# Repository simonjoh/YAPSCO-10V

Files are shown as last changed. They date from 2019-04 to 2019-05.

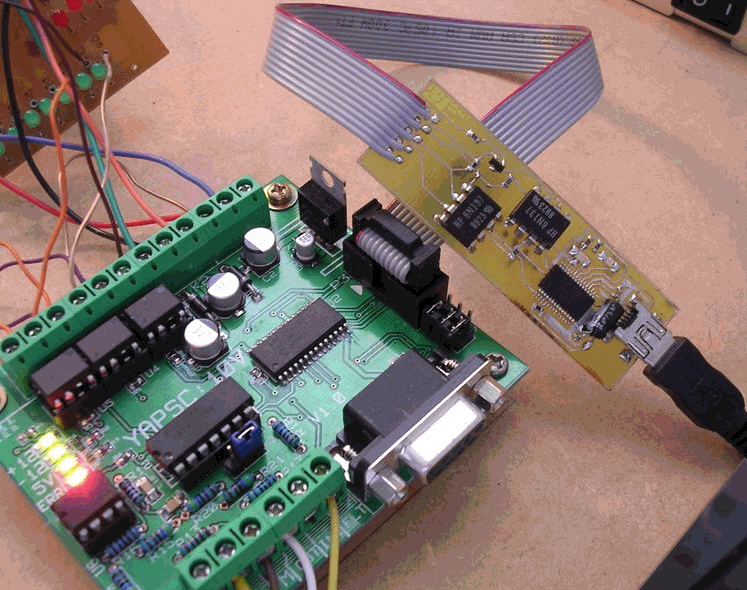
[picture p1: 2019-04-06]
YAPSC.10V Doc/PCB/2side-photo2.gif

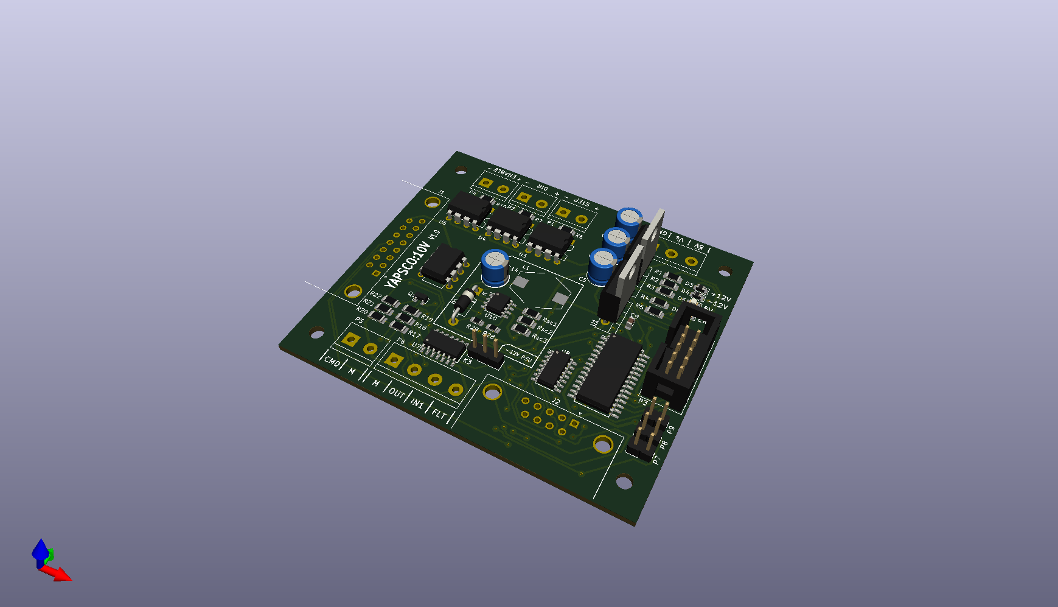
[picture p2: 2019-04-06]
schema_pcb/YAPSCO.png

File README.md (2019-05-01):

# YAPSCO-10V
Modification of the YAPSC:10V with onboard -12V supply.

The board has the same outer dimensions and mounting hole positions as YAPSC:10V, so a drop-in replacement should be quite easy.

## Specifications
* Input voltage +12V..+24V
* Same as YAPSC:10V

## Schematic and PCB
Most of the schematic symbols have been updated with new ones from Kicad's library.

Some PCB footprints have been replaced with surface mounted versions to be able to squash in the -12V supply while keeping the board outline and mounting holes the same as YAPSC:10V.

The DB15 connector footprint has also been added to the PCB layout so that it can easily be soldered onto the board if needed.

The PCB now includes a DC-DC voltage inverter set to -12V, but can be adjusted as necessary with 2 feedback resistors (R28, R29). Component values for the DC-DC converter can be calculated with the SMath sheet "Calc MC33063.sm".

## Everything else
The firmware has not been modified and connectors are generally kept in the original places.

## Disclaimer
The board is being manufactured and therefore have not been tested yet. The only thing I have tested, is the DC-DC controller on a breadboard, but since everything has mainly been kept as the original it should just work right out of the box, right? :)

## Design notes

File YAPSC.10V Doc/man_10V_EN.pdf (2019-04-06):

# YAPSC : 10V

### Users' manual

Yet Another dsPic Servo Controller – 10V Page 1/15

## Table Of Content

Page 2/15 Yet Another dsPic Servo Controller – 10V

## 1 Introduction - before you start

YAPSC:10V allows the use of analog-operated servo amplifiers, either torque or speed controlled. This board takes STEP/DIR position command from the PC (MACH3, EMC etc.), position feedback from a quadrature encoder, and outputs an analog command to the servo amp.
Please note the difference between YAPSC and YAPSC:10V. These two projects share a part of the dsPic's source code but the manuals are different! YAPSC is a board WITH a power stage to control DC servos; whereas YAPSC:10V has no power stage and cannot drive a servomotor without a servo power amplifier.
If you are looking for the DC servomotor controller, this is not the right manual you are looking into! You will find links at the end of this document for each versions of YAPSC.
Below are the two big scheme of YAPSC:10V application:

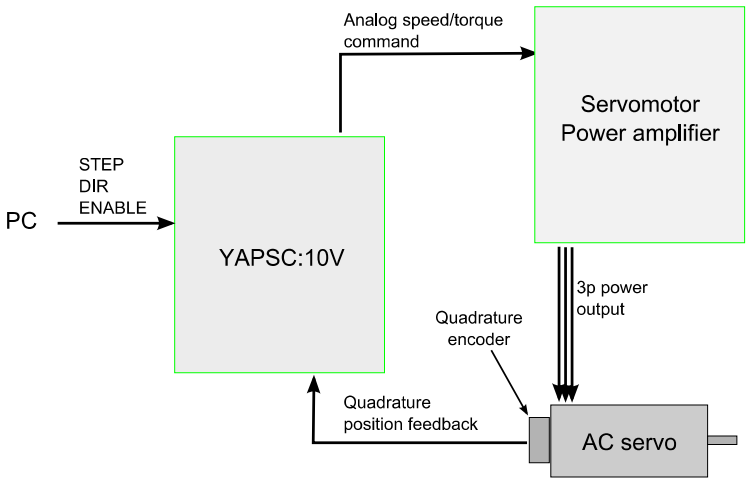
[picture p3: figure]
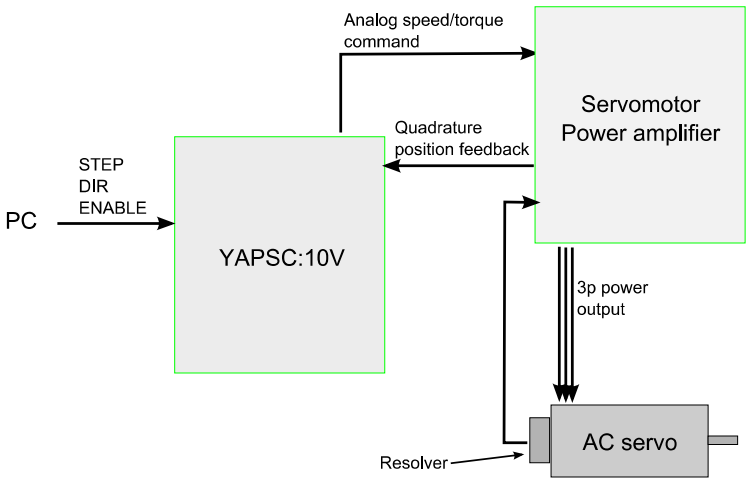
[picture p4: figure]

## 2 Features

- Takes position feedback from quadrature encoder on the servo (resolvers cannot be used directly but some amps can output quadrature signals from the resolver feedback)
- Compatible with both torque and speed controlled amps
- Takes STEP/DIR command from PC
- ENABLE signal from PC can disable the amp
- Output amplitude can be selected from +/-0V to +/-10V, to feed +/-10V or +/-5V amps
- Jumper selected TTL or differential quadrature encoder input
- FAULT input from the servo amp
- Reset/ENABLE output to the servo amp
- One additional input for future use
- Programmable max error limit : 0 (disabled) to 32768
- PID tuning program for linux, windows (and probably Mac OS) : YTT (under development)
- STEP/DIR input multiplier (allows faster speed)
- 1MHz max step and encoder rate!

## 3 Physical Description

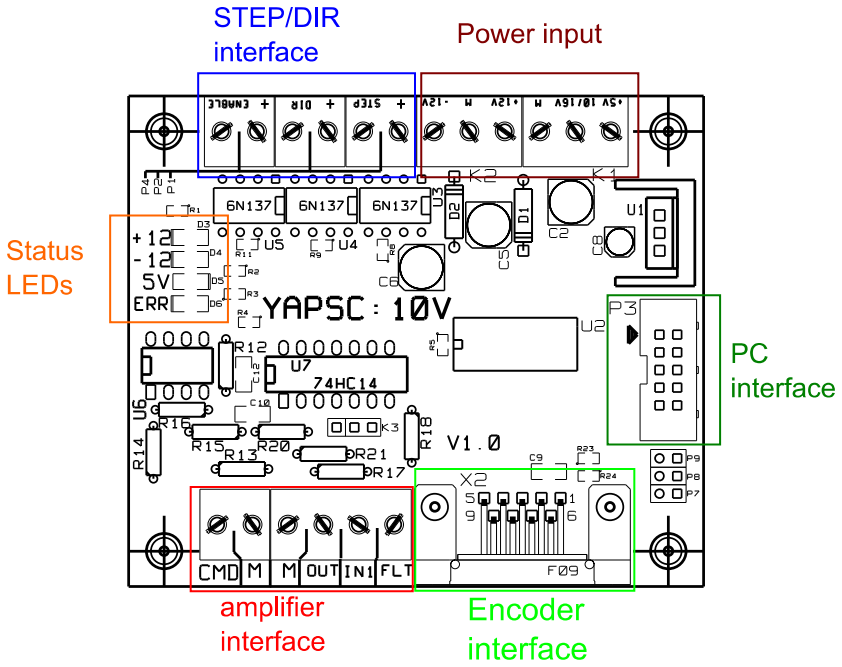
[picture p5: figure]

## 3.1 Status LEDs

There are 4 LEDs on the board:

Page 4/15 Yet Another dsPic Servo Controller – 10V

3.1.1 +12V
Green LED. Lit when the OpAmp +12V supply is present.

3.1.2 -12V
Green LED. Lit when the OpAmp -12V supply is present.

3.1.3 5V
Green LED. Lit when the dsPIC +5V is present

### 3.1.4 ERR

This LED is dark under normal operation.

### 3.1.4.1 Power up

During power up, ERR LED is lit during he power-up procedure. If the ERR led is stuck and the amplifier is disabled, connect the Prog. Key and open a serial terminal. Cycle the power OFF and ON. You should read the initialization status and see where the process blocks.

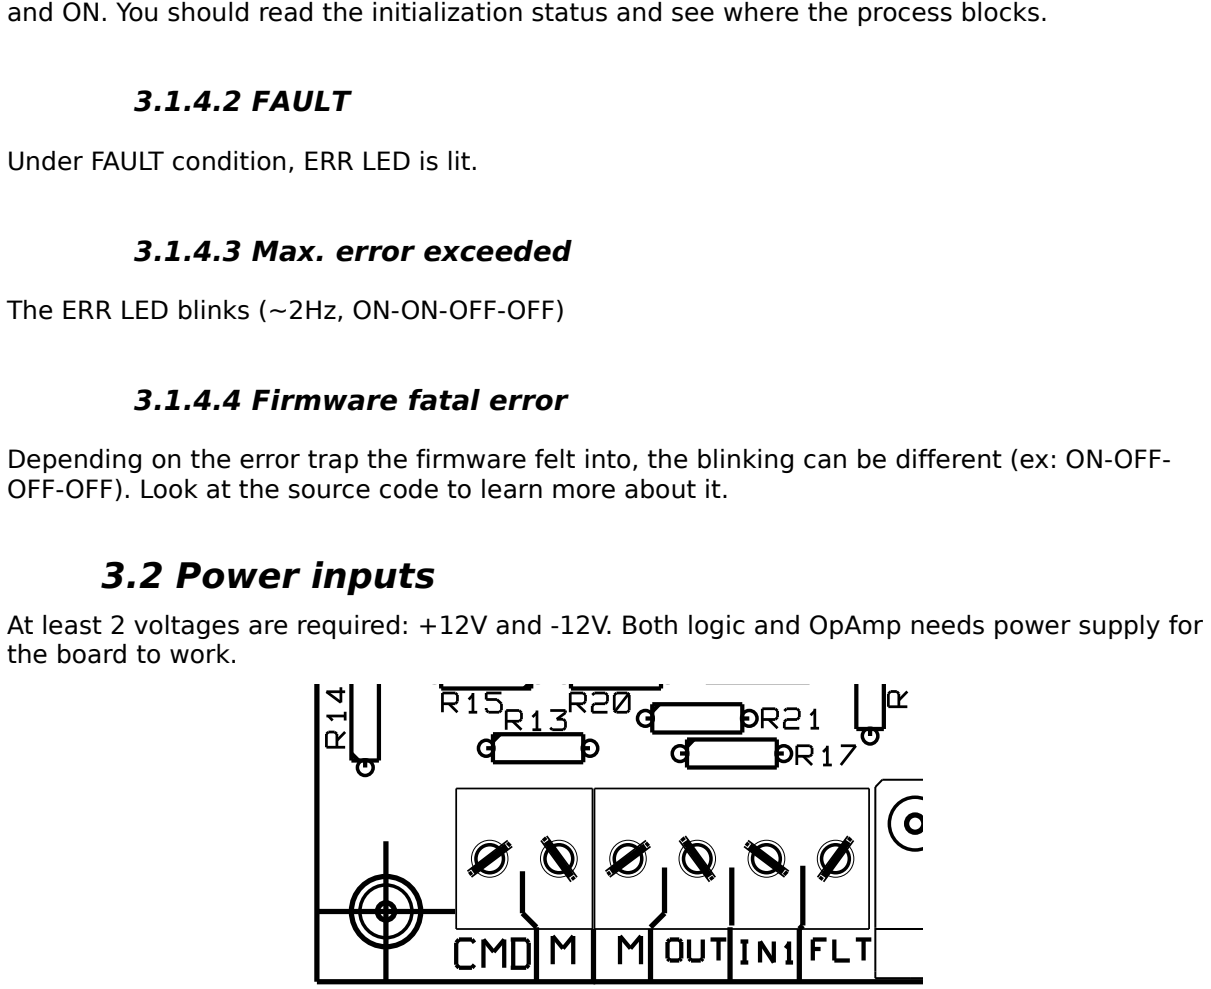
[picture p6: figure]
3.1.4.2 FAULT; Under FAULT condition, ERR LED is lit.; 3.1.4.3 Max. error exceeded; 3.1.4.4 Firmware fatal error; 3.2 Power inputs; the board to work.

The ERR LED blinks (~2Hz, ON-ON-OFF-OFF)

Depending on the error trap the firmware felt into, the blinking can be different (ex: ON-OFF-OFF-OFF). Look at the source code to learn more about it.

At least 2 voltages are required: +12V and -12V. Both logic and OpAmp needs power supply for

### 3.2.1 K1

K1 is the logic power supply input.

3.2.1.1 +5V

Logic +5V supply. You can connect it directly to a 5V power source, or use the regulated voltage from 10 to 16V input to supply 5V to other logic/boards. The board's power consumption is maximum 300mA plus encoder consumption (generally ~10-20mA)

### 3.2.1.2 M

Common ground

3.2.1.3 10/16V

Input to the LM7805 voltage regulator. 10 to 16V, max 300mA + encoder consumption

### 3.2.2 K2

K2 is the OpAmp supply voltage input.

3.2.2.1 +12V

12 to 16V positive supply. 30mA max consumption

3.2.2.2 -12V

-16 to -12V negative supply. 30mA max consumption

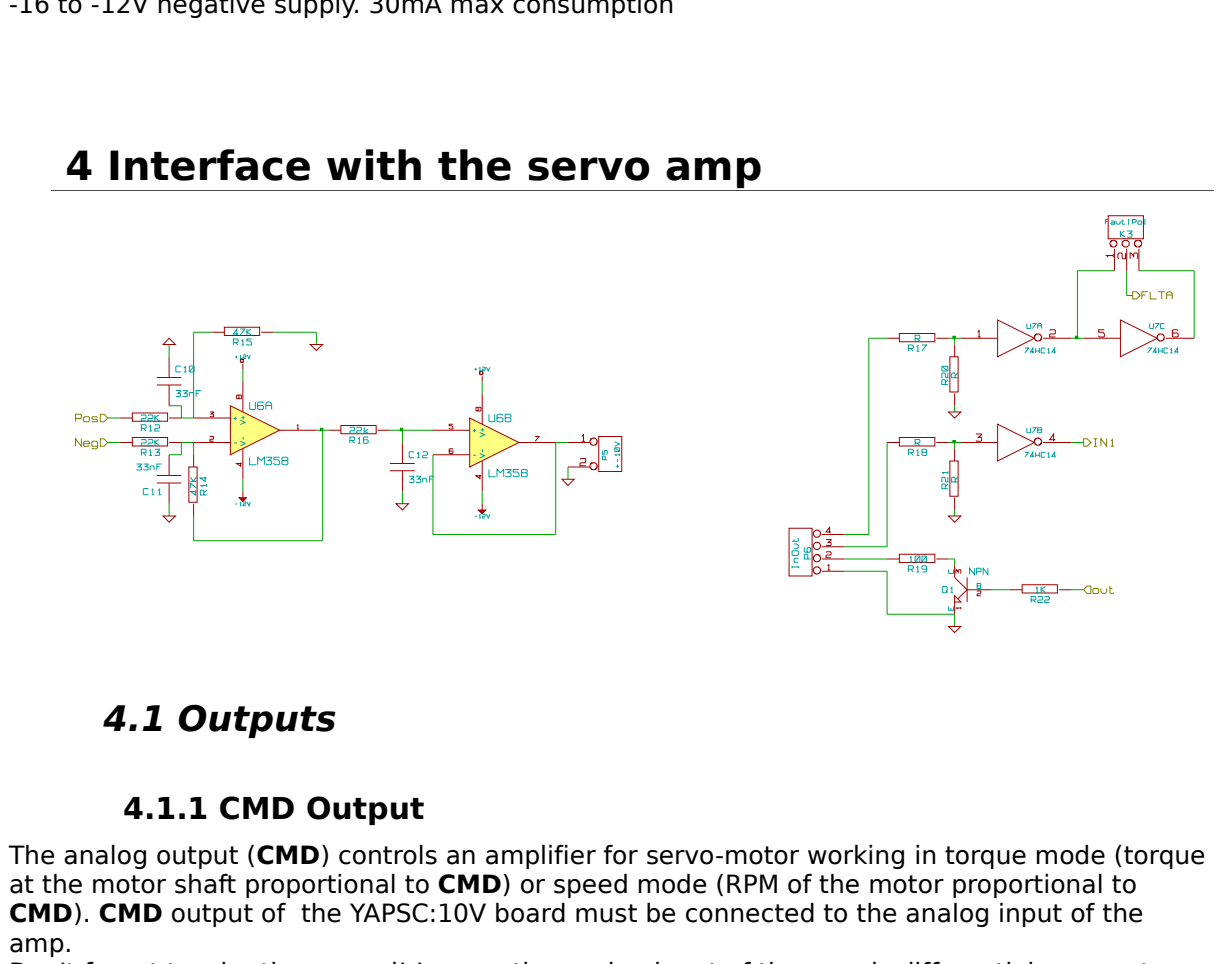
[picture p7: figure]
4 Interface with the servo amp; 4.1 Outputs; 4.1.1 CMD Output; amp.

The analog output (CMD) controls an amplifier for servo-motor working in torque mode (torque at the motor shaft proportional to CMD) or speed mode (RPM of the motor proportional to CMD). CMD output of the YAPSC:10V board must be connected to the analog input of the

Don't forget to wire the ground! In case the analog input of the amp is differential, connect

Page 6/15 Yet Another dsPic Servo Controller – 10V

CMD to the + (positive) input and the ground M on the – (negative) input of the amp. For differential input amp, you must use two wires, one for the ground M and the other for CMD. Those two cables must be at least twisted, but it's better to have them twisted and shielded. You must, independently of those two wires, link a cable (min. 0,5mm² section area) between M and the amp's ground

### 4.1.2 OUT output

The “OUT” output is an open-collector output, designed to drive 0-30V 100mA loads, such as relays etc.
To come : example schematics

### 4.1.2.1 Enable/Reset

Under running conditions (i.e motor is powered and YAPSC taking STEP/DIR commands), OUT is forced low.
If YAPSC is disabled (see section 5.2.1), the OUT output is floating.
If a FAULT condition is detected (look in section 4.2.1), then OUT will be floating and the ERROR led will blink.

## 4.2 Inputs

There are two Schmitt-trigger (digital) inputs which can be configured.
By changing the values of (R17,R20) and (R18/R21) the two inputs can work with 5V, 12V or 24V logic:
5V logic | 24V logic
R17 = R18 = 1KΩ | R17 = R18 = 39,2KΩ
R20 = R21 = 47KΩ | R20 = R21 = 10KΩ
Low level : L = 2,5V | Low level : L = 12V
High level : H = 3V | High level : H = 15V

### 4.2.1 FLT input

This input is the feedback from the servo amp. In case that a problem (overtemp, overvoltage, ...) is detected by the amp, it can notify YAPSC. On a FAULT condition, YAPSC:10V goes into disabled mode : CMD=0 and the STEP/DIR commands are ignored.
FLT input can be configured either to be active-low or active high:
Polarity : | Active high | Active low
K3 strap position: | 1 – 2 | 2 – 3
Fault operation: | If FLT is High, FAULT condition If FLT is Low, normal operation | If FLT is Low, FAULT condition If FLT is High, normal operation

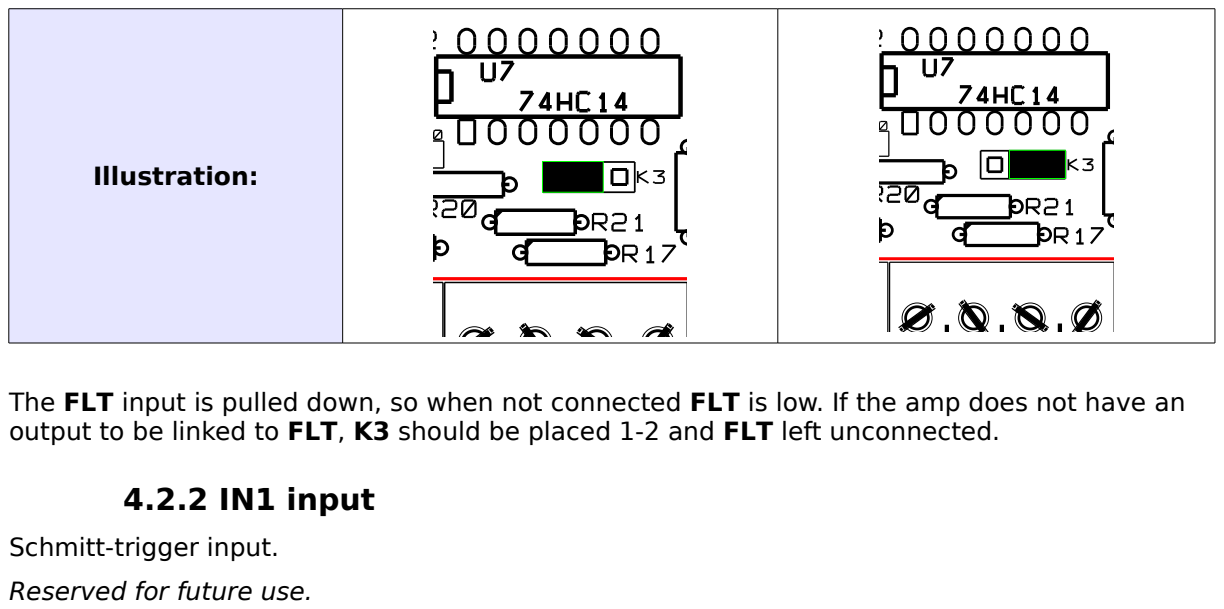
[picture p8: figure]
Illustration:; 4.2.2 IN1 input; Schmitt-trigger input.; Reserved for future use.

The FLT input is pulled down, so when not connected FLT is low. If the amp does not have an output to be linked to FLT, K3 should be placed 1-2 and FLT left unconnected.

## 5 Interface with the computer

## 5.1 HE10

HE10 connector P3 provides all the following:

### 5.1.1 RS232 port

For configuring YAPSC:10V via a serial port terminal (I.e hyperterminal on Windows) or via YTT (read section 8.1).
Pin 6 (RXD) : data in
Pin 5 (TXD) : data out
Port configuration : 9600bps, 8n, 1stop, no flow control.
The RS232 pins are NOT optoisolated! For maximum security, please | use the
optoisolated USB prog. | key.

### 5.1.2 ICSP

The dsPIC30F4012 can be programmed via an ICD2, pickit2 or other programming tool. The program can also be debugged under operation with Microchip's ICD2/3 (or other compatible tools).
Pin 2 : MCLR Master Clear

Page 8/15 Yet Another dsPic Servo Controller – 10V

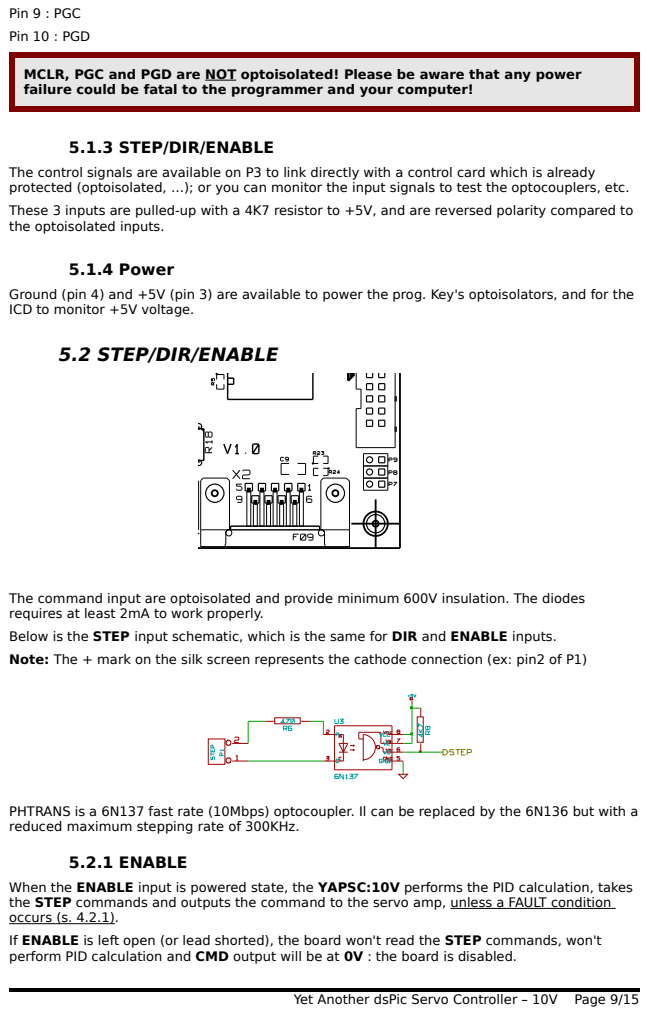
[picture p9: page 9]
Pin 9 : PGC; Pin 10 : PGD; 5.1.4 Power; 5.2.1 ENABLE

MCLR, PGC and PGD are NOT optoisolated! Please be aware that any power
failure could be fatal to the programmer and your computer!

5.1.3 STEP/DIR/ENABLE

The control signals are available on P3 to link directly with a control card which is already
protected (optoisolated, …); or you can monitor the input signals to test the optocouplers, etc.
These 3 inputs are pulled-up with a 4K7 resistor to +5V, and are reversed polarity compared to
the optoisolated inputs.

Ground (pin 4) and +5V (pin 3) are available to power the prog. Key's optoisolators, and for the
ICD to monitor +5V voltage.

5.2 STEP/DIR/ENABLE

The command input are optoisolated and provide minimum 600V insulation. The diodes
requires at least 2mA to work properly.
Below is the STEP input schematic, which is the same for DIR and ENABLE inputs.
Note: The + mark on the silk screen represents the cathode connection (ex: pin2 of P1)

PHTRANS is a 6N137 fast rate (10Mbps) optocoupler. Il can be replaced by the 6N136 but with a
reduced maximum stepping rate of 300KHz.

When the ENABLE input is powered state, the YAPSC:10V performs the PID calculation, takes
the STEP commands and outputs the command to the servo amp, unless a FAULT condition
occurs (s. 4.2.1 ).
If ENABLE is left open (or lead shorted), the board won't read the STEP commands, won't
perform PID calculation and CMD output will be at 0V : the board is disabled.

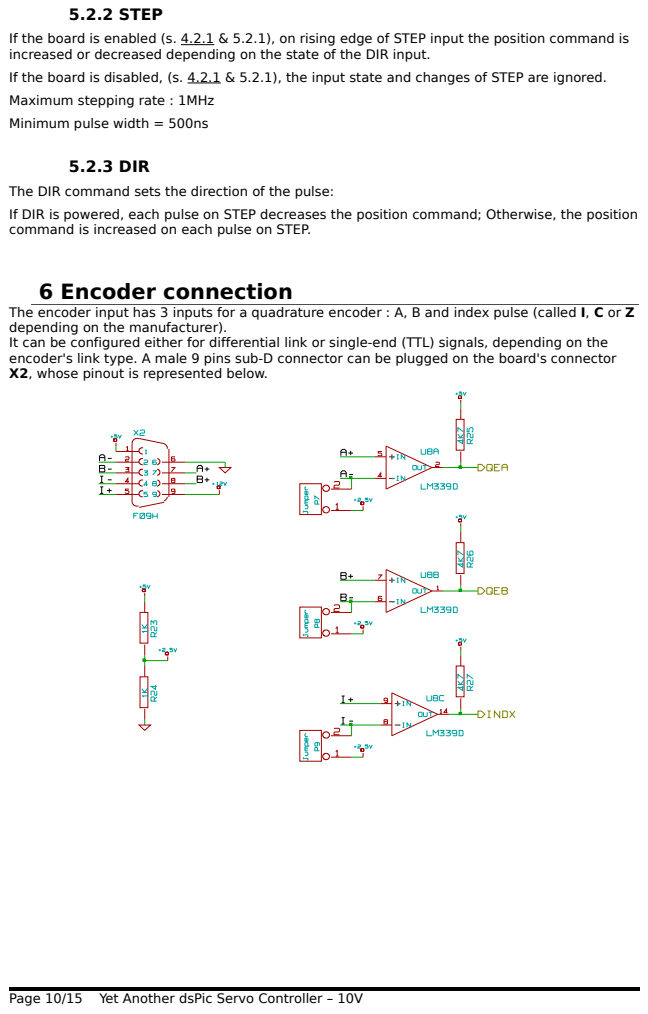
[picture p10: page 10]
5.2.2 STEP; 5.2.3 DIR

If the board is enabled (s. 4.2.1 & 5.2.1), on rising edge of STEP input the position command is
increased or decreased depending on the state of the DIR input.
If the board is disabled, (s. 4.2.1 & 5.2.1), the input state and changes of STEP are ignored.
Maximum stepping rate : 1MHz
Minimum pulse width = 500ns

The DIR command sets the direction of the pulse:
If DIR is powered, each pulse on STEP decreases the position command; Otherwise, the position
command is increased on each pulse on STEP.

6 Encoder connection
The encoder input has 3 inputs for a quadrature encoder : A, B and index pulse (called I, C or Z
depending on the manufacturer).
It can be configured either for differential link or single-end (TTL) signals, depending on the
encoder's link type. A male 9 pins sub-D connector can be plugged on the board's connector
X2, whose pinout is represented below.

Page 10/15 Yet Another dsPic Servo Controller – 10V

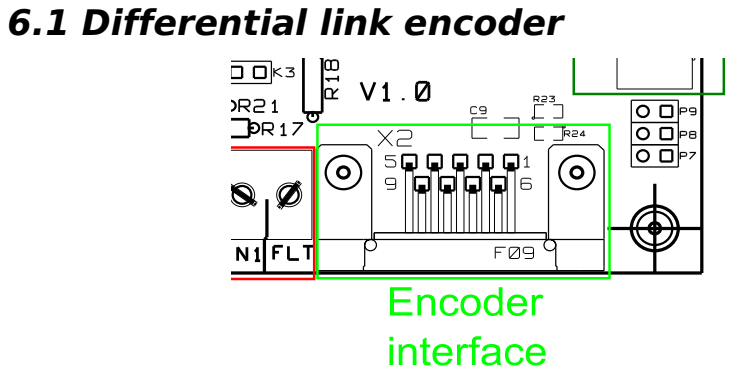
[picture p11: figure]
6.1 Differential link encoder

- Remove P7 , P8 and P9
- Link A+/A- to the A output of the encoder, B+/B- to the B output of the encoder
- Link I+/I- to the index output C (can be called Z or I) of the encoder, if present
- Link the ground (or negative supply) of the encoder to the sub-D9's pin number 6
- Depending on the supply voltage required by the encoder, link the +5V or +12V (sub-D9's pins 1 or 9) to the positive supply of the encoder
- Once the encoder cord is fully linked, you can plug the connector onto YAPSC:10V's X2 connector.
You should note that:
- If the encoder allows it (check the corresponding datasheet), link a 120Ohms resistor between A+ and A-; between B+ and B- and between I+ and I- as close as possible to the sub-D9 plug used to make the encoder cord. This will help noise immunity.
- Contrary to +5V supply, the +12V supply is NOT a regulated voltage. It comes directly from K1 connector, so you should check that this voltage meets the encoder's specifications.

## 6.2 TTL Encoder

- Place P7, P8 et P9
- Link A+ th the A output of the encoder, B+ to the B output of the encoder. A- and Bare not linked
- Link I+ to the index output of the encoder (Called C, I or Z) if present on the encoder. Iis not linked
- Link the ground (or negative supply) of the encoder to the sub-D9's pin number 6
- Depending on the supply voltage required by the encoder, link the +5V or +12V (sub-D9's pins 1 or 9) to the positive supply of the encoder
- Once the encoder cord is fully linked, you can plug the connector onto YAPSC:10V's X2

connector.

Do NEVER link a differential link encoder while P7, P8 or P9 are in position! The encoder could be damaged if that was the case!

Note:
- You may have to place capacitors (100uF+1uF electro +100nF ceramic) between the encoder's ground and positive supply if the cables between the encoder and YAPSC:10V is long, and more generally if the encoder is sensitive to electrical noise.
- If the encoder needs a very precise +5V regulated power supply, do not use the 5V output (pin 1) but rather use a LM7805 type regulator and its capacitors as close to the encoder as possible. This regulator will be powered by the +12V (pin9).

## 7 Configuring the board

Each commands are sent trough the RS232 port and validated by pressing the [ENTER] key (serial port sends “\r\n” to the board).
This section refers to RS232-terminal configuration; A dedicated software called YTT (YAPSC Tuning Tool) eases the configuration of the board (look in section 8).
Here are the available commands:

### 7.1.1 PID gains

P sets the P gain (usally P=0,001 to 0,1)
I sets the I gain (usally I=0,0001 to 0,01) D sets the D gain (usally P=0,0001 to 0,01) EXAMPLE:
P0,001
I0,0001
D0

### 7.1.2 Maximal error

This parameter is the error (in pulses; ie lines *4) over which the amp is disabled (no torque). Send the L command :
L1024
Sets the max. error to 1024 pulses (=256 lines)

NOTE: following command disables the max error monitoring. Please do not use this mode unless you are absolutely sure of what you are doing!
L0

NOTE: When the maximum error is reached, the ERROR led blinks and the error is reported on the serial port. To reset the board, you have to cycle power OFF and ON or to reset the board (short MCLR and GND pins, see section 5.1.2)

Page 12/15 Yet Another dsPic Servo Controller – 10V

### 7.1.3 Maximum output

To match the output swing to any type of amplifier, the output swing can be limited. The output swing is expressed in percent of 10,5V:
M50
Will set the output swing to +5,25/-5,25V
M95
Sets the output swing to +10V/-10V

### 7.1.4 STEP input multiplier

For fast displacements, the 1MHz STEP limit of the interpolator's maximum STEP rate (ex: MACH3 is limited to ~30-40KHz on the parallel port) may not be enough. If the resolution can be reduced, you can set the multiplier to a higher value than 1.
EXAMPLE:
X2
Multiply the STEP inputs by 2. Each pulse on STEP will move the motor's position of 2 pulses (½ line)
EXEMPLE:
X-1
Inverts the direction. It is equivalent to invert the DIR input.

## 8 Annex

## 8.1 YTT (YAPSC Tuning Tool)

YTT is currently under development and has no web page. Check the YAPSC:10V (http://www.cnczone.com/forums/showthread.php?t=74532) tread for latest news.

## 8.2 YAPSC

The first version of YAPSC is a DC servomotor controller equipped with a power stage. Links:
- Original tread on the French forum usinages.com : www.usinages.com/carte-servos-adspic-t648.html (http://www.usinages.com/carte-servos-a-dspic-t648.html)
- YAPSC-related stuff on my web page (French) : http://max-mod-shop.com/index.php?option=com_content&view=category&id=17:-yapsc&Itemid=4&layout=default (http://max-mod-shop.com/index.php?option=com_content&view=category&id=17:-yapsc&Itemid=4&layout=default)
- dspic-servo tread on cnczone.com : http://www.cnczone.com/forums/showthread.php?t=40940 (http://www.cnczone.com/forums/showthread.php?t=40940)

## 8.3 dspic-servo

This is the original work from Lawrence Glaister I based YAPSC on. It is located at http://www.members.shaw.ca/swstuff/dspic-servo.html

## 8.4 Licence

Unless specified, the project files are released under GPL3. Read the included file gpl-3.0-standalone.html

This manual is NOT under GPL, I (Charles-Henri Maximilien MOUSSET) reserve all right on it. Copying or modifying in any way (partially or entirely) this manual's content is forbidden unless I explicitly authorize you to do so.
You can freely distribute this manual under the same condition, unmodified and without any material of financial compensation.

## 8.5 Contact

Maximilien MOUSSET
max-mod@max-mod-shop.com
PM “MaX-MoD” on cnczone,com PM “MaX-MoD” on usinages.com

Page 14/15 Yet Another dsPic Servo Controller – 10V

## Document Rev

Date | Description
04/04/09 | Corrected board silkscreen on power input connector

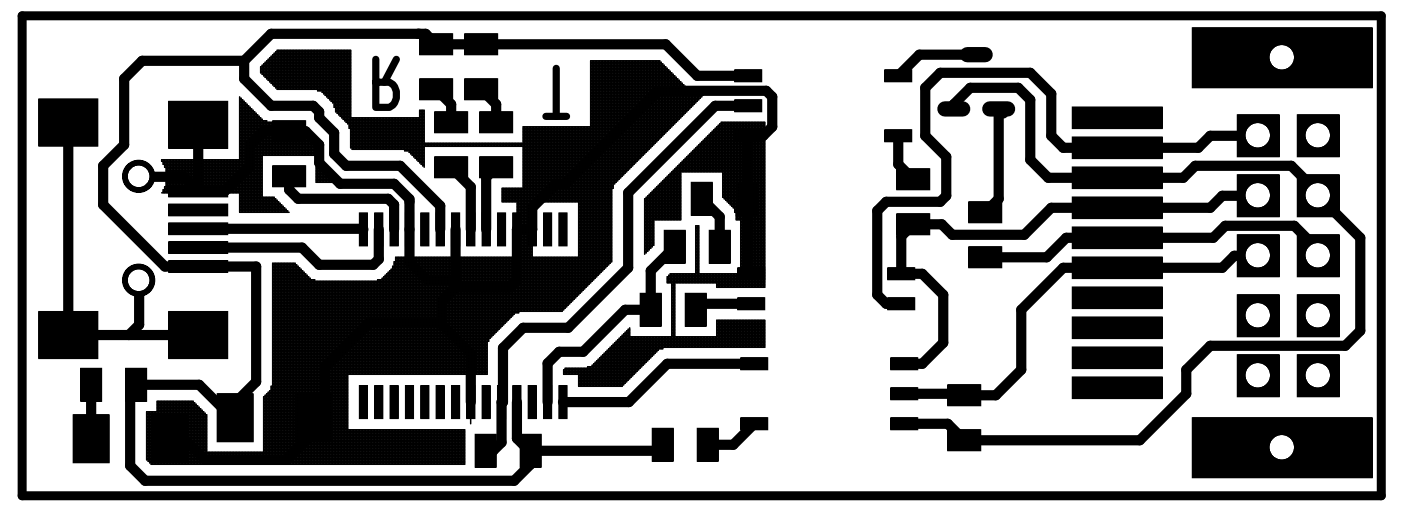
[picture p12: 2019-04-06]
YAPSC.10V Doc/PCB/USB.bmp

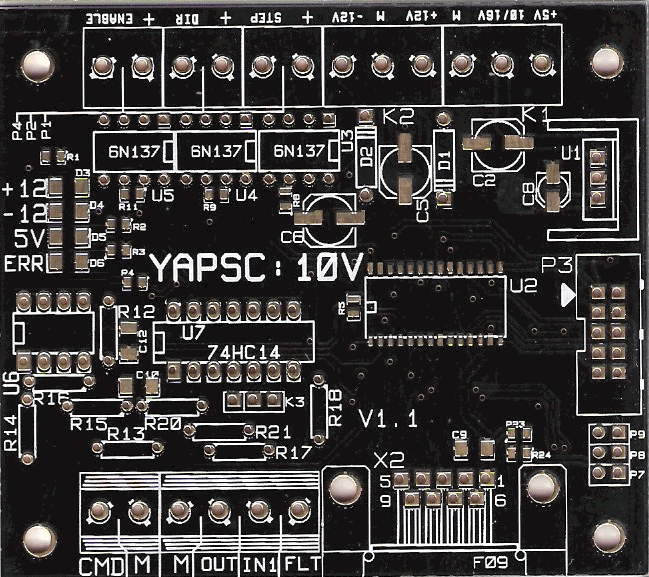
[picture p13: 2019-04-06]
YAPSC.10V Doc/PCB/1side-photo1.gif

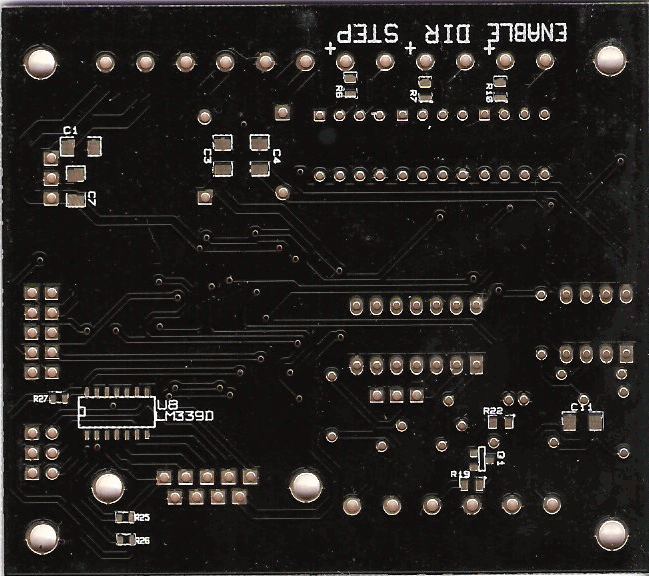
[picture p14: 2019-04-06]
YAPSC.10V Doc/PCB/2side-photo1.gif

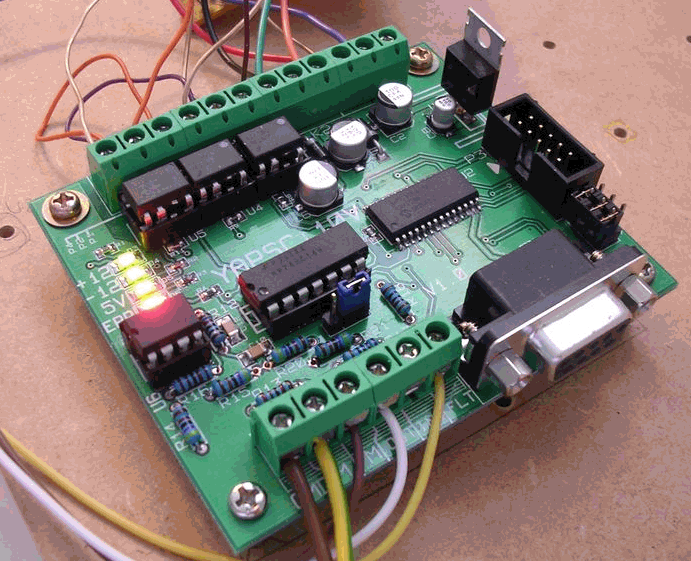
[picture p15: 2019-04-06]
YAPSC.10V Doc/PCB/1side-photo2.gif

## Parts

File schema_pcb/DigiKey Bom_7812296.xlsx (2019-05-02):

Manufacturer Part Number | Manufacturer | Digi-Key Part Number | Customer Reference | Reference Designator | Packaging | Part Status | Quantity | Unit Price | Extended Price | Quantity Available | Mfg Std Lead Time | Description | RoHS Status | Lead Free Status | REACH Status | US Tariff Status
OSTTC032162 | On Shore Technology Inc. | ED2610-ND |  |  | Bulk | Active | 1 | 5.61 | kr.5.61 | 52062 | 12 Weeks | TERM BLK 3P SIDE ENT 5.08MM PCB | RoHS Compliant | Lead free | REACH Unaffected | Tariff Applied
OSTTC022162 | On Shore Technology Inc. | ED2609-ND |  |  | Bulk | Active | 6 | 5.28 | kr.31.68 | 63751 | 12 Weeks | TERM BLK 2P SIDE ENT 5.08MM PCB | RoHS Compliant | Lead free | REACH Unaffected | Tariff Applied
885012207069 | Wurth Electronics Inc. | 732-8058-1-ND |  |  | Cut Tape (CT) | Active | 3 | 0.73 | kr.2.19 | 3880 | 37 Weeks | CAP CER 0.033UF 25V X7R 0805 | RoHS Compliant | Lead free | REACH Unaffected
885012207083 | Wurth Electronics Inc. | 732-8065-1-ND |  |  | Cut Tape (CT) | Active | 1 | 0.73 | kr.0.73 | 1263 | 37 Weeks | CAP CER 330PF 50V X7R 0805 | RoHS Compliant | Lead free | REACH Unaffected
LTST-S220GKT | Lite-On Inc. | 160-1218-1-ND |  |  | Cut Tape (CT) | Active | 3 | 1.78 | kr.5.34 | 85968 | 10 Weeks | LED GREEN CLEAR SMD R/A | RoHS Compliant | Lead free | REACH Unaffected | Tariff Applied
LTST-C170KFKT | Lite-On Inc. | 160-1413-1-ND |  |  | Cut Tape (CT) | Active | 1 | 2.05 | kr.2.05 | 107434 | 10 Weeks | LED ORANGE CLEAR SMD | RoHS Compliant | Lead free | Not Available | Tariff Applied
1N5819 A0G | Taiwan Semiconductor Corporation | 1N5819A0GCT-ND |  |  | Cut Tape (CT) | Active | 1 | 1.85 | kr.1.85 | 18405 | 16 Weeks | DIODE SCHOTTKY 40V 1A DO204AL | RoHS Compliant | Lead free | Not Available | Tariff Applied
61300311121 | Wurth Electronics Inc. | 732-5316-ND |  |  | Bag | Active | 1 | 0.92 | kr.0.92 | 131243 | 14 Weeks | CONN HEADER VERT 3POS 2.54MM | RoHS Compliant | Lead free | REACH Unaffected
SDR1005-471KL | Bourns Inc. | SDR1005-471KLCT-ND |  |  | Cut Tape (CT) | Active | 1 | 5.74 | kr.5.74 | 3226 | 14 Weeks | FIXED IND 470UH 450MA 1.7 OHM | RoHS Compliant | Lead free | REACH Unaffected | Tariff Applied
PR20205VBDN | METZ CONNECT USA Inc. | 1849-1002-ND |  |  | Bag | Active | 1 | 1.06 | kr.1.06 | 3004 | 9 Weeks | CONN HEADER VERT 10POS 2.54MM | RoHS Compliant | Lead free | Not Available
PREC002SAAN-RC | Sullins Connector Solutions | S1012EC-02-ND |  |  | Bag | Active | 3 | 0.4 | kr.1.20 | 15669 | Not Available | CONN HEADER VERT 2POS 2.54MM | RoHS Compliant | Lead free | REACH Unaffected
QPC02SXGN-RC | Sullins Connector Solutions | S9337-ND |  |  | Bag | Active | 3 | 0.66 | kr.1.98 | 497414 | 5 Weeks | CONN JUMPER SHORTING .100" GOLD | RoHS Compliant | Lead free | REACH Unaffected
MMBT3904-TP | Micro Commercial Co | MMBT3904TPMSCT-ND |  |  | Cut Tape (CT) | Active | 1 | 0.66 | kr.0.66 | 2768177 | 16 Weeks | TRANS NPN 40V 0.2A SOT23 | RoHS Compliant | Lead free | REACH Unaffected | Tariff Applied
RMCF1206JT100R | Stackpole Electronics Inc | RMCF1206JT100RCT-ND |  |  | Cut Tape (CT) | Active | 1 | 0.66 | kr.0.66 | 314101 | 17 Weeks | RES 100 OHM 5% 1/4W 1206 | RoHS Compliant | Lead free | REACH Unaffected | Tariff Applied
RMCF1206JT10K0 | Stackpole Electronics Inc | RMCF1206JT10K0CT-ND |  |  | Cut Tape (CT) | Active | 3 | 0.66 | kr.1.98 | 1054635 | 17 Weeks | RES 10K OHM 5% 1/4W 1206 | RoHS Compliant | Lead free | REACH Unaffected | Tariff Applied
RMCF1206JT1K00 | Stackpole Electronics Inc | RMCF1206JT1K00CT-ND |  |  | Cut Tape (CT) | Active | 3 | 0.66 | kr.1.98 | 342948 | 17 Weeks | RES 1K OHM 5% 1/4W 1206 | RoHS Compliant | Lead free | REACH Unaffected | Tariff Applied
CR0805-JW-102ELF | Bourns Inc. | CR0805-JW-102ELFCT-ND |  |  | Cut Tape (CT) | Active | 1 | 0.66 | kr.0.66 | 900 | 16 Weeks | RES SMD 1K OHM 5% 1/8W 0805 | RoHS Compliant | Lead free | REACH Unaffected
RMCF1206JT22K0 | Stackpole Electronics Inc | RMCF1206JT22K0CT-ND |  |  | Cut Tape (CT) | Active | 3 | 0.66 | kr.1.98 | 152137 | 17 Weeks | RES 22K OHM 5% 1/4W 1206 | RoHS Compliant | Lead free | REACH Unaffected | Tariff Applied
RMCF1206JT2K20 | Stackpole Electronics Inc | RMCF1206JT2K20CT-ND |  |  | Cut Tape (CT) | Active | 2 | 0.66 | kr.1.32 | 182276 | 17 Weeks | RES 2.2K OHM 5% 1/4W 1206 | RoHS Compliant | Lead free | REACH Unaffected | Tariff Applied
RMCF1206JT470R | Stackpole Electronics Inc | RMCF1206JT470RCT-ND |  |  | Cut Tape (CT) | Active | 5 | 0.66 | kr.3.30 | 56580 | 17 Weeks | RES 470 OHM 5% 1/4W 1206 | RoHS Compliant | Lead free | REACH Unaffected | Tariff Applied
RMCF1206JT47K0 | Stackpole Electronics Inc | RMCF1206JT47K0CT-ND |  |  | Cut Tape (CT) | Active | 2 | 0.66 | kr.1.32 | 86478 | 17 Weeks | RES 47K OHM 5% 1/4W 1206 | RoHS Compliant | Lead free | REACH Unaffected | Tariff Applied
RMCF1206JT4K70 | Stackpole Electronics Inc | RMCF1206JT4K70CT-ND |  |  | Cut Tape (CT) | Active | 6 | 0.66 | kr.3.96 | 228218 | 17 Weeks | RES 4.7K OHM 5% 1/4W 1206 | RoHS Compliant | Lead free | REACH Unaffected | Tariff Applied
RMCF0805FT8K66 | Stackpole Electronics Inc | RMCF0805FT8K66CT-ND |  |  | Cut Tape (CT) | Active | 1 | 0.66 | kr.0.66 | 40949 | 17 Weeks | RES 8.66K OHM 1% 1/8W 0805 | RoHS Compliant | Lead free | REACH Unaffected
RMCF1206JG39K0 | Stackpole Electronics Inc | RMCF1206JG39K0CT-ND |  |  | Cut Tape (CT) | Active | 2 | 0.66 | kr.1.32 | 9849 | 17 Weeks | RES 39K OHM 5% 1/4W 1206 | RoHS Compliant | Lead free | REACH Unaffected | Tariff Applied
RMCF1206JT1R10 | Stackpole Electronics Inc | RMCF1206JT1R10CT-ND |  |  | Cut Tape (CT) | Active | 3 | 0.66 | kr.1.98 | 7820 | 17 Weeks | RES 1.1 OHM 5% 1/4W 1206 | RoHS Compliant | Lead free | REACH Unaffected | Tariff Applied
6N137 | Lite-On Inc. | 160-1791-ND |  |  | Tube | Active | 3 | 5.35 | kr.16.05 | 22281 | 10 Weeks | OPTOISO 5KV 1CH OPEN COLL 8DIP | RoHS Compliant | Lead free | Not Available
74HC14D | Toshiba Semiconductor and Storage | 74HC14DCT-ND |  |  | Cut Tape (CT) | Active | 1 | 2.64 | kr.2.64 | 2641 | 8 Weeks | IC INVERTER SCHMITT 6CH 14SOIC | RoHS Compliant | Lead free | Not Available
SCD7812BTG | ON Semiconductor | SCD7812BTGOS-ND |  |  | Tube | Active | 1 | 3.17 | kr.3.17 | 2164 | 2 Weeks | IC VOLT REG 1A 12V TO220 | RoHS Compliant | Lead free | REACH Unaffected
SCD7805BTG | ON Semiconductor | SCD7805BTGOS-ND |  |  | Tube | Active | 1 | 3.17 | kr.3.17 | 2087 | 2 Weeks | IC VOLT REG 1A 5V TO220 | RoHS Compliant | Lead free | REACH Unaffected | Tariff Applied
LM339DR | Texas Instruments | 296-1013-1-ND |  |  | Cut Tape (CT) | Active | 1 | 2.38 | kr.2.38 | 49120 | 6 Weeks | IC QUAD DIFF COMP 14-SOIC | RoHS Compliant | Lead free | REACH Unaffected
LM358PE4 | Texas Instruments | 296-36107-5-ND |  |  | Tube | Active | 1 | 2.64 | kr.2.64 | 3655 | 6 Weeks | IC OPAMP GP 700KHZ 8DIP | RoHS Compliant | Lead free | REACH Unaffected
MC33063ADR | Texas Instruments | 296-17763-1-ND |  |  | Cut Tape (CT) | Active | 1 | 4.09 | kr.4.09 | 297524 | 6 Weeks | IC REG BUCK BST ADJ 1.5A 8SOIC | RoHS Compliant | Lead free | REACH Unaffected
DSPIC30F4012-30I/SO | Microchip Technology | DSPIC30F401230ISO-ND |  |  | Tube | Active | 1 | 34.91 | kr.34.91 | 63 | 5 Weeks | IC MCU 16BIT 48KB FLASH 28SOIC | RoHS Compliant | Lead free | REACH Unaffected
CC0805ZRY5V9BB104 | Yageo | 311-1361-1-ND |  |  | Cut Tape (CT) | Active | 4 | 0.86 | kr.3.44 | 1728888 | 16 Weeks | CAP CER 0.1UF 50V Y5V 0805 | RoHS Compliant | Lead free | REACH Unaffected
A-DF 09 A/KG-T2S | Assmann WSW Components | AE10921-ND |  |  | Tray | Active | 1 | 5.08 | kr.5.08 | 30085 | 20 Weeks | CONN D-SUB RCPT 9POS R/A SOLDER | RoHS Compliant | Lead free | REACH Unaffected | Tariff Eligible
860020473008 | Wurth Electronics Inc. | 732-8825-1-ND |  |  | Cut Tape (CT) | Active | 4 | 0.92 | kr.3.68 | 1083 | 24 Weeks | CAP ALUM 100UF 20% 25V RADIAL | RoHS Compliant | Lead free | REACH Unaffected | Tariff Applied
Total |  |  |  |  |  |  |  |  | kr.163.38

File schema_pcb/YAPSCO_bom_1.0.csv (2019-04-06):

Component | Description | Part | References | Value | Footprint | Quantity Per PCB | Datasheet
1 | Unpolarized capacitor | C | C1 C3 C4 C9 | 100nF | C_0805_2012Metric_Pad1.15x1.40mm_HandSolder | 4
2 | Polarized capacitor | CP | C5 C13 C14 C15 | 100uF | CP_Radial_D6.3mm_P2.50mm | 4
3 | Unpolarized capacitor | C | C10 C11 C12 | 33nF | C_0805_2012Metric_Pad1.15x1.40mm_HandSolder | 3
4 | Unpolarized capacitor | C | C8 | 360p | C_0805_2012Metric_Pad1.15x1.40mm_HandSolder | 1
5 | Light emitting diode | LED | D3 | +12 | D_0805_2012Metric_Pad1.15x1.40mm_HandSolder | 1
6 | Light emitting diode | LED | D4 | -12 | D_0805_2012Metric_Pad1.15x1.40mm_HandSolder | 1
7 | Schottky diode | D_Schottky | D1 | 1N5819 | D_DO-41_SOD81_P10.16mm_Horizontal | 1 | ~
8 | Light emitting diode | LED | D6 | LED | LED_0805_2012Metric_Pad1.15x1.40mm_HandSolder | 1
9 | Light emitting diode | LED | D5 | LED 5V | LED_0805_2012Metric_Pad1.15x1.40mm_HandSolder | 1
10 | Generic connector, single row, 01x03, script generated (kicad-library-utils/schlib/autogen/connector/) | Conn_01x03_Male | K3 | FautlPol | PinHeader_1x03_P2.54mm_Vertical | 1
11 | Generic screw terminal, single row, 01x03, script generated (kicad-library-utils/schlib/autogen/connector/) | Screw_Terminal_01x03 | K1 | Supply | TerminalBlock_bornier-3_P5.08mm | 1
12 | Inductor | L | L1 | 1m | L_Bourns-SRR1005 | 1 | ~
13 | Generic screw terminal, single row, 01x02, script generated (kicad-library-utils/schlib/autogen/connector/) | Screw_Terminal_01x02 | P5 | +-10V | TerminalBlock_bornier-2_P5.08mm | 1
14 | Generic connector, double row, 02x05, odd/even pin numbering scheme (row 1 odd numbers, row 2 even numbers), script generated (kicad-library-utils/schlib/autogen/connector/) | Conn_02x05_Odd_Even | P3 | CONN | IDC-Header_2x05_P2.54mm_Vertical | 1
15 | Generic screw terminal, single row, 01x02, script generated (kicad-library-utils/schlib/autogen/connector/) | Screw_Terminal_01x02 | P2 | DIR | TerminalBlock_bornier-2_P5.08mm | 1
16 | Generic screw terminal, single row, 01x02, script generated (kicad-library-utils/schlib/autogen/connector/) | Screw_Terminal_01x02 | P4 | ENABLE | TerminalBlock_bornier-2_P5.08mm | 1
17 | Generic screw terminal, single row, 01x04, script generated (kicad-library-utils/schlib/autogen/connector/) | Screw_Terminal_01x04 | P6 | InOut | TerminalBlock_bornier-4_P5.08mm | 1
18 | Jumper, 2-pole, open | Jumper_2_Open | P7 P8 P9 | Jumper | PinHeader_1x02_P2.54mm_Vertical | 3
19 | Generic screw terminal, single row, 01x02, script generated (kicad-library-utils/schlib/autogen/connector/) | Screw_Terminal_01x02 | P1 | STEP | TerminalBlock_bornier-2_P5.08mm | 1
20 | NPN transistor, base/emitter/collector | Q_NPN_BEC | Q1 | NPN | SOT-23 | 1
21 | Resistor | R | R19 | 100 | R_1206_3216Metric_Pad1.42x1.75mm_HandSolder | 1
22 | Resistor | R | R5 | 10K | R_1206_3216Metric_Pad1.42x1.75mm_HandSolder | 1
23 | Resistor | R | R22 R23 R24 | 1K | R_1206_3216Metric_Pad1.42x1.75mm_HandSolder | 3
24 | Resistor | R | R29 | 1K | R_0805_2012Metric_Pad1.15x1.40mm_HandSolder | 1 | ~
25 | Resistor | R | R12 R13 R16 | 22K | R_1206_3216Metric_Pad1.42x1.75mm_HandSolder | 3
26 | Resistor | R | R1 R2 | 2K2 | R_1206_3216Metric_Pad1.42x1.75mm_HandSolder | 2
27 | Resistor | R | R3 R4 R6 R7 R10 | 470 | R_1206_3216Metric_Pad1.42x1.75mm_HandSolder | 5
28 | Resistor | R | R14 R15 | 47K | R_1206_3216Metric_Pad1.42x1.75mm_HandSolder | 2
29 | Resistor | R | R8 R9 R11 R25 R26 R27 | 4K7 | R_1206_3216Metric_Pad1.42x1.75mm_HandSolder | 6
30 | Resistor | R | R28 | 8K6 | R_0805_2012Metric_Pad1.15x1.40mm_HandSolder | 1 | ~
31 | Resistor | R | R17 R18 R20 R21 | R | R_1206_3216Metric_Pad1.42x1.75mm_HandSolder | 4
32 | Resistor | R | Rsc1 Rsc2 Rsc3 | 1R | R_1206_3216Metric_Pad1.42x1.75mm_HandSolder | 3 | ~
33 |  | 6N137 | U3 U4 U5 | 6N137 | DIP-8_W7.62mm | 3
34 | Hex inverter schmitt trigger | 74HC14 | U7 | 74HC14 | SOIC-14_3.9x8.7mm_P1.27mm | 1 | http://www.nxp.com/documents/data_sheet/74HC_HCT04.pdf
35 | Positive 1A 35V Linear Regulator, Fixed Output 5V, TO-220 | LM7805_TO220 | U1 | 7805 | TO-220-3_Vertical | 1 | http://www.fairchildsemi.com/ds/LM/LM7805.pdf
36 | Positive 1.5A 35V Linear Regulator, Fixed Output 12V, TO-220/TO-263/TO-252 | L7812 | U9 | L7812 | TO-220-3_Vertical | 1 | http://www.st.com/content/ccc/resource/technical/document/datasheet/41/4f/b3/b0/12/d4/47/88/CD00000444.pdf/files/CD00000444.pdf/jcr:content/translations/en.CD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
37 | Quad Differential Comparators, DIP-14/SOIC-14/SSOP-14 | LM339 | U8 | LM339D | SOIC-14_3.9x8.7mm_P1.27mm | 1 | http://www.ti.com/lit/ds/symlink/lm339.pdf
38 | Low-Power, Dual Operational Amplifiers, DIP-8/SOIC-8/TO-99-8 | LM358 | U6 | LM358 | DIP-8_W7.62mm | 1 | http://www.ti.com/lit/ds/symlink/lm358.pdf
39 | 1.5A, step-up/down/inverting switching regulator, 3-40V Vin, 100kHz, SO-8 | MC33063AD | U10 | MC33063AD | SOIC-8_3.9x4.9mm_P1.27mm | 1 | http://www.onsemi.com/pub_link/Collateral/MC34063A-D.PDF
40 |  | DSPIC30F4012-20E_SO | U2 | dsPIC30F4012 | SOIC-28W_7.5x17.9mm_P1.27mm | 1 | Microchip
Component Groups: | 40
Component Count: | 72
Fitted Components: | 72
Number of PCBs: | 1
Total components: | 72
Schematic Version: | 1.0
Schematic Date: | 2019-03-30
BoM Date: | 05-04-2019 17:39:44
Schematic Source: | E:\OneDrive\Dokumenter\DIY\Projekter\HJF CNC\YAPSC.10V\schema_pcb\current\YAPSCO.sch
KiCad Version: | Eeschema (5.1.0)-1

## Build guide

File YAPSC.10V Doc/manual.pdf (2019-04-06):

# YAPSC : 10V

### Users' manual

Yet Another dsPic Servo Controller – 10V Page 1/11

## Table Of Content

Page 2/11 Yet Another dsPic Servo Controller – 10V

## 1 Introduction - before you start

YAPSC:10V allows the use of analog-operated servo amplifiers, either torque or speed controlled. This board takes STEP/DIR position command from the PC (MACH3, EMC etc.), position feedback from a quadrature encoder, and outputs an analog command to the servo amp.
Please note the difference between YAPSC and YAPSC:10V. These two projects share a part of the dsPic's source code but the manuals are different! YAPSC is a board WITH a power stage to control DC servos; whereas YAPSC:10V has no power stage and cannot drive a servomotor without a servo power amplifier.
If you are looking for the DC servomotor controller, this is not the right manual you are looking into! You will find links at the end of this document for each versions of YAPSC.

## 2 Features

- Takes position feedback from quadrature encoder on the servo (resolvers cannot be used directly but some amps can output quadrature signals from the resolver feedback)
- Compatible with both torque and speed controlled amps
- Takes STEP/DIR command from PC
- ENABLE signal from PC can disable the amp
- Output amplitude can be selected from +/-0V to +/-10V, to feed +/-10V or +/-5V amps
- Jumper selected TTL or differential quadrature encoder input
- FAULT input from the servo amp
- Reset/ENABLE output to the servo amp
- One additional input for future use
- Programmable max error limit : 0 (disabled) to 32768
- PID tuning program for linux, windows (and probably Mac OS) : YTT (under development)
- STEP/DIR input multiplier (allows faster speed)
- 1MHz max step and encoder rate!

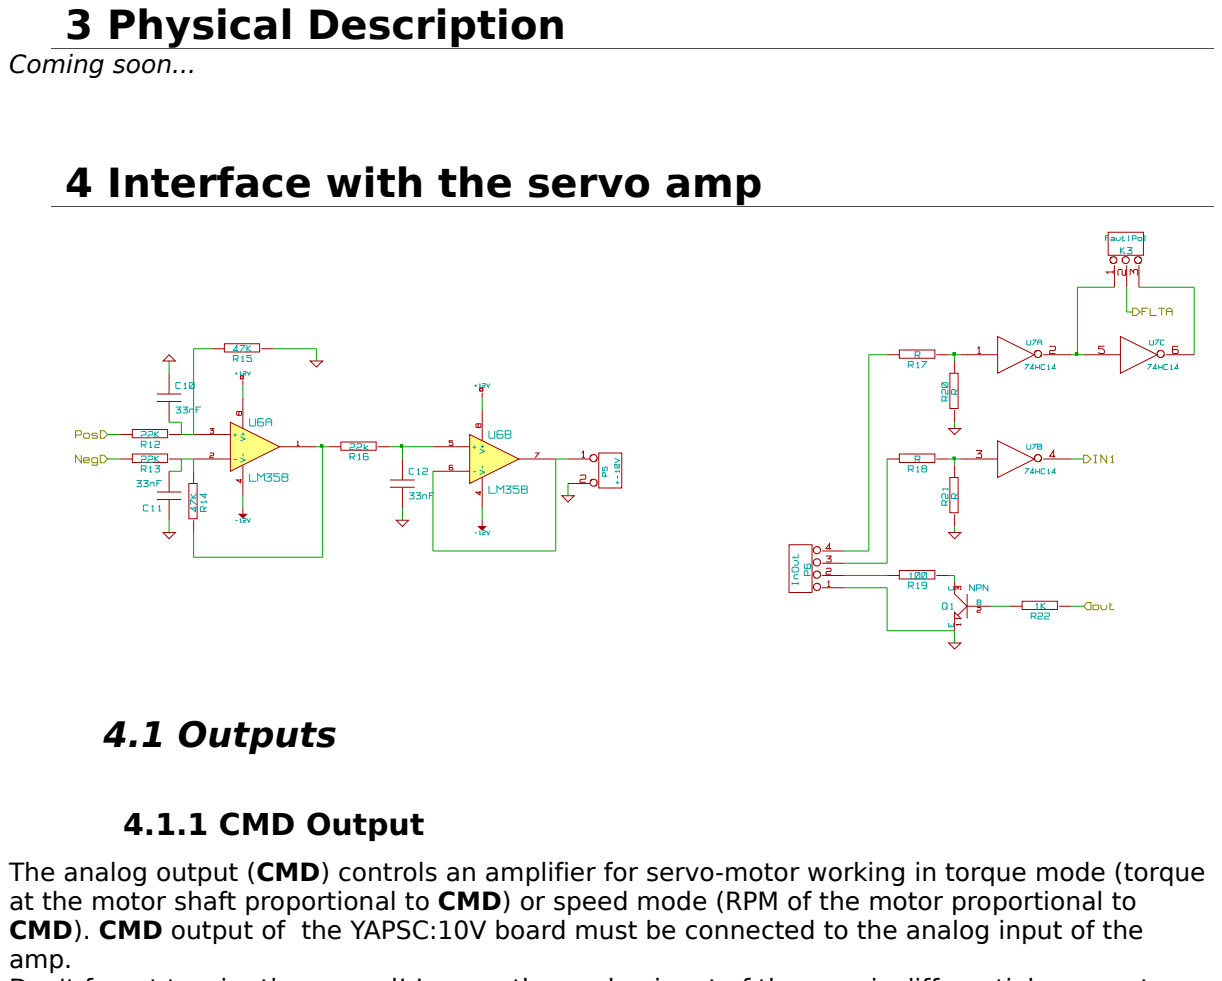
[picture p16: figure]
3 Physical Description; Coming soon...; 4 Interface with the servo amp; 4.1 Outputs; 4.1.1 CMD Output; amp.

The analog output (CMD) controls an amplifier for servo-motor working in torque mode (torque at the motor shaft proportional to CMD) or speed mode (RPM of the motor proportional to CMD). CMD output of the YAPSC:10V board must be connected to the analog input of the

Don't forget to wire the ground! In case the analog input of the amp is differential, connect CMD to the + (positive) input and the ground M on the – (negative) input of the amp. For differential input amp, you must use two wires, one for the ground M and the other for CMD. Those two cables must be at least twisted, but it's better to have them twisted and shielded. You must, independently of those two wires, link a cable (min. 0,5mm² section area) between M and the amp's ground

Page 4/11 Yet Another dsPic Servo Controller – 10V

### 4.1.2 OUT output

The “OUT” output is an open-collector output, designed to drive 0-30V 100mA loads, such as relays etc.
To come : example schematics

### 4.1.2.1 Enable/Reset

Under running conditions (i.e motor is powered and YAPSC taking STEP/DIR commands), OUT is forced low.
If YAPSC is disabled (see section 5.2.1), the OUT output is floating.
If a FAULT condition is detected (look in section 4.2.1), then OUT will be floating and the ERROR led will blink.

## 4.2 Inputs

There are two Schmitt-trigger (digital) inputs which can be configured.
By changing the values of (R17,R20) and (R18/R21) the two inputs can work with 5V, 12V or 24V logic:
5V logic | 24V logic
R17 = R18 = 1KΩ | R17 = R18 = 39,2KΩ
R20 = R21 = 47KΩ | R20 = R21 = 10KΩ
Low level : L = 2,5V | Low level : L = 12V
High level : H = 3V | High level : H = 15V

### 4.2.1 FLT input

This input is the feedback from the servo amp. In case that a problem (overtemp, overvoltage, ...) is detected by the amp, it can notify YAPSC. On a FAULT condition, YAPSC:10V goes into disabled mode : CMD=0 and the STEP/DIR commands are ignored.
FLT input can be configured either to be active-low or active high:
Polarity : | Active high | Active low
K3 strap position | 1 – 2 | 2 – 3
Fault: | If FLT is High, FAULT condition If FLT is Low, normal operation | If FLT is Low, FAULT condition If FLT is High, normal operation

The FLT input is pulled down, so when not connected FLT is low. If the amp does not have an output to be linked to FLT, K3 should be placed 1-2 and FLT left unconnected.

### 4.2.2 IN1 input

Schmitt-trigger input.
Reserved for fut | ure use.

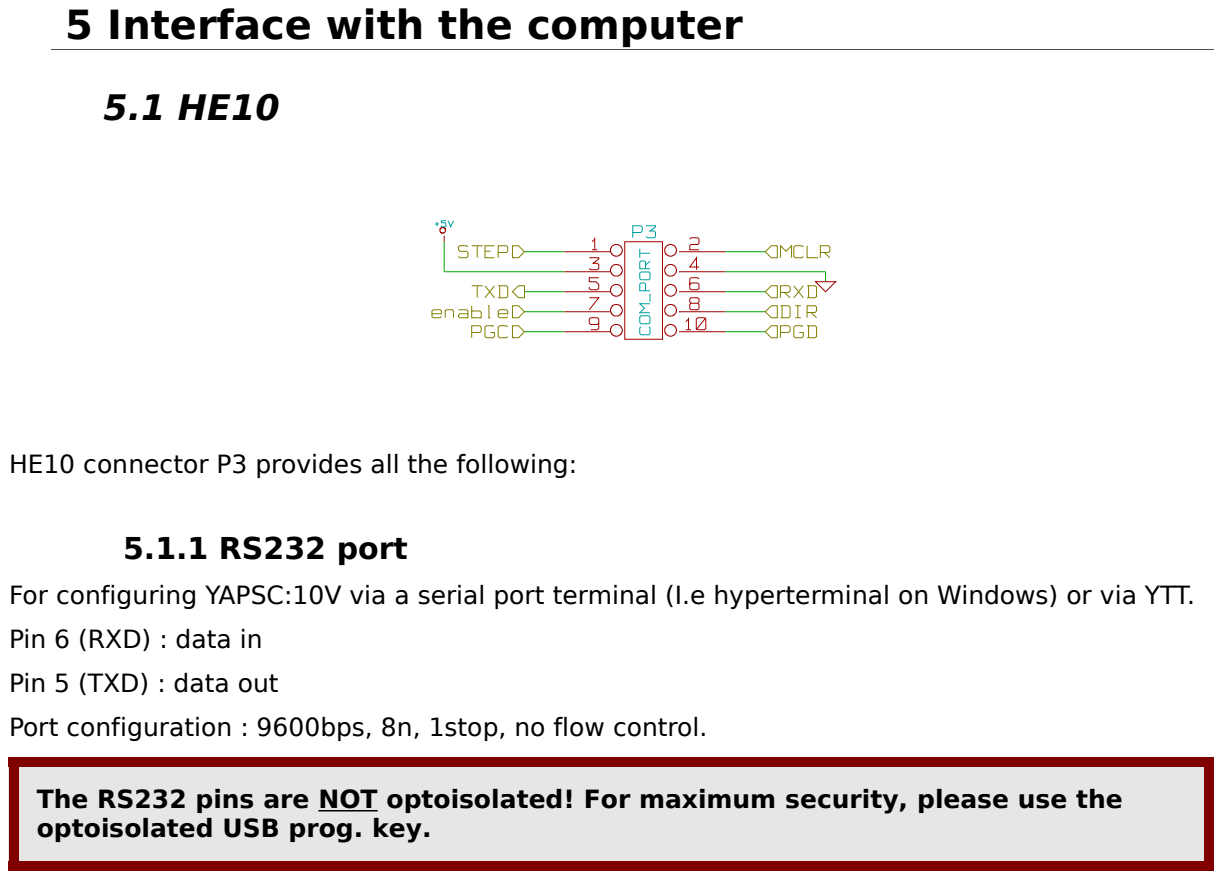
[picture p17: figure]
5 Interface with the computer; 5.1.1 RS232 port; Pin 6 (RXD) : data in; Pin 5 (TXD) : data out; optoisolated USB prog. key.

HE10 connector P3 provides all the following:

For configuring YAPSC:10V via a serial port terminal (I.e hyperterminal on Windows) or via YTT.

Port configuration : 9600bps, 8n, 1stop, no flow control.

The RS232 pins are NOT optoisolated! For maximum security, please use the

### 5.1.2 ICSP

The dsPIC30F4012 can be programmed via an ICD2, pickit2 or other programming tool. The program can also be debugged under operation with Microchip's ICD2/3 (or other compatible tools).
Pin 2 : MCLR Master Clear
Pin 9 : PGC
Pin 10 : PGD

MCLR, PGC and PGD are NOT optoisolated! Please be aware that any power failure could be fatal to the programmer and your computer!

### 5.1.3 STEP/DIR/ENABLE

The control signals are available on P3 to link directly with a control card which is already protected (optoisolated, …); or you can monitor the input signals to test the optocouplers, etc. These 3 inputs are pulled-up with a 4K7 resistor to +5V, and are reversed polarity compared to the optoisolated inputs.

### 5.1.4 Power

Ground (pin 4) and +5V (pin 3) are available to power the prog. Key's optoisolators, and for the ICD to monitor +5V voltage.

Page 6/11 Yet Another dsPic Servo Controller – 10V

## 5.2 STEP/DIR/ENABLE

The command input are optoisolated and provide minimum 600V insulation. The diodes requires at least 2mA to work properly.
Below is the STEP input schematic, which is the same for DIR and ENABLE inputs.

PHTRANS is a 6N137 fast rate (10Mbps) optocoupler. Il can be replaced by the 6N136 but with a reduced maximum stepping rate of 300KHz.

### 5.2.1 ENABLE

When the ENABLE input is powered state, the YAPSC:10V performs the PID calculation, takes the STEP commands and outputs the command to the servo amp, unless a FAULT condition occurs (s. 4.2.1 ).
If ENABLE is left open (or lead shorted), the board won't read the STEP commands, won't perform PID calculation and CMD output will be at 0V : the board is disabled.

### 5.2.2 STEP

If the board is enabled (s. 4.2.1 & 5.2.1), on rising edge of STEP input the position command is increased or decreased depending on the state of the DIR input.
If the board is disabled, (s. 4.2.1 & 5.2.1), the input state and changes of STEP are ignored. Maximum stepping rate : 1MHz
Minimum pulse width = 500ns

### 5.2.3 DIR

The DIR command sets the direction of the pulse:
If DIR is powered, each pulse on STEP decreases the position command; Otherwise, the position command is increased on each pulse on STEP.

## 6 Encoder connection

The encoder input has 3 inputs for a quadrature encoder : A, B and index pulse (called I, C or Z depending on the manufacturer).
It can be configured either for differential link or single-end (TTL) signals, depending on the encoder's link type. A male 9 pins sub-D connector can be plugged on the board's connector X2, whose pinout is represented below.

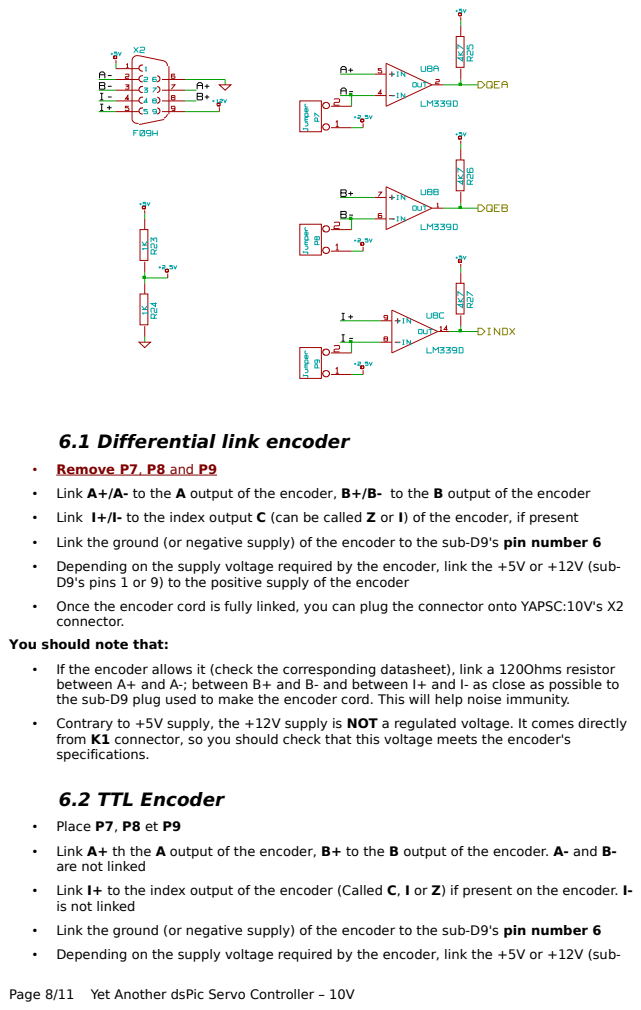
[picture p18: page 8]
6.2 TTL Encoder

6.1 Differential link encoder

• Remove P7 , P8 and P9
• Link A+/A- to the A output of the encoder, B+/B- to the B output of the encoder
• Link I+/I- to the index output C (can be called Z or I) of the encoder, if present
• Link the ground (or negative supply) of the encoder to the sub-D9's pin number 6
• Depending on the supply voltage required by the encoder, link the +5V or +12V (sub-
D9's pins 1 or 9) to the positive supply of the encoder
• Once the encoder cord is fully linked, you can plug the connector onto YAPSC:10V's X2
connector.

You should note that:
• If the encoder allows it (check the corresponding datasheet), link a 120Ohms resistor
between A+ and A-; between B+ and B- and between I+ and I- as close as possible to
the sub-D9 plug used to make the encoder cord. This will help noise immunity.
• Contrary to +5V supply, the +12V supply is NOT a regulated voltage. It comes directly
from K1 connector, so you should check that this voltage meets the encoder's
specifications.

• Place P7, P8 et P9
• Link A+ th the A output of the encoder, B+ to the B output of the encoder. A- and B-
are not linked
• Link I+ to the index output of the encoder (Called C, I or Z) if present on the encoder. I-
is not linked

Page 8/11 Yet Another dsPic Servo Controller – 10V

D9's pins 1 or 9) to the positive supply of the encoder
- Once the encoder cord is fully linked, you can plug the connector onto YAPSC:10V's X2 connector.

Do NEVER link a differential link encoder while P7, P8 or P9 are in position! The encoder could be damaged if that was the case!

Note:
- You may have to place capacitors (100uF+1uF electro +100nF ceramic) between the encoder's ground and positive supply if the cables between the encoder and YAPSC:10V is long, and more generally if the encoder is sensitive to electrical noise.
- If the encoder needs a very precise +5V regulated power supply, do not use the 5V output (pin 1) but rather use a LM7805 type regulator and its capacitors as close to the encoder as possible. This regulator will be powered by the +12V (pin9).

## 7 Configuring the board

Each commands are sent trough the RS232 port and validated by pressing the [ENTER] key (serial port sends “\r\n” to the board).
This section refers to RS232-terminal configuration; A dedicated software called YTT (YAPSC Tuning Tool) eases the configuration of the board (look in section 8).
Here are the available commands:

### 7.1.1 PID gains

P sets the P gain (usally P=0,001 to 0,1)
I sets the I gain (usally I=0,0001 to 0,01) D sets the D gain (usally P=0,0001 to 0,01) EXAMPLE:
P0,001
I0,0001
D0

### 7.1.2 Maximal error

This parameter is the error (in pulses; ie lines *4) over which the amp is disabled (no torque). Send the L command :
L1024
Sets the max. error to 1024 pulses (=256 lines)
NOTE: following command disables the max error monitoring. Please do not use th | is mod | e
unless you are absolutely sore of what you are doing!
L0

NOTE: When the maximum error is reached, the ERROR led blinks and the error is reported on the serial port. To reset the board, you have to cycle power OFF and ON or to reset the board (short MCLR and GND pins, see section 5.1.2)

### 7.1.3 Maximum output

To match the output swing to any type of amplifier, the output swing can be limited. The output swing is expressed in percent of 10,5V:
M50
Will set the output swing to +5,25/-5,25V
M95
Sets the output swing to +10V/-10V

### 7.1.4 STEP input multiplier

For fast displacements, the 1MHz STEP limit of the interpolator's maximum STEP rate (ex: MACH3 is limited to ~30-40KHz on the parallel port) may not be enough. If the resolution can be reduced, you can set the multiplier to a higher value than 1.
EXAMPLE:
X2
Multiply the STEP inputs by 2. Each pulse on STEP will move the motor's position of 2 pulses (½ line)
EXEMPLE:
X-1
Inverts the direction. It is equivalent to invert the DIR input.

## 8 Annex

## 8.1 YTT (YAPSC Tuning Tool)

YTT is currently under development and has no web page. Check the YAPSC:10V (http://www.cnczone.com/forums/showthread.php?t=74532) tread for latest news.

## 8.2 YAPSC

The first version of YAPSC is a DC servomotor controller equipped with a power stage. Links:
- Original tread on the French forum usinages.com : www.usinages.com/carte-servos-adspic-t648.html (http://www.usinages.com/carte-servos-a-dspic-t648.html)
- YAPSC-related stuff on my web page (French) : http://max-mod-shop.com/index.php?option=com_content&view=category&id=17:-yapsc&Itemid=4&layout=default (http://max-mod-shop.com/index.php?option=com_content&view=category&id=17:-yapsc&Itemid=4&layout=default)
- dspic-servo tread on cnczone.com : http://www.cnczone.com/forums/showthread.php?t=40940 (http://www.cnczone.com/forums/showthread.php?t=40940)

## 8.3 dspic-servo

This is the original work from Lawrence Glaister I based YAPSC on. It is located at http://www.members.shaw.ca/swstuff/dspic-servo.html

## 8.4 Licence

Unless specified, the project files are released under GPL3. Read the included file gpl-3.0-standalone.html

Page 10/11 Yet Another dsPic Servo Controller – 10V

This manual is NOT under GPL, I (Charles-Henri Maximilien MOUSSET) reserve all right on it. Copying or modifying in any way (partially or entirely) this manual's content is forbidden unless I explicitly authorize you to do so.
You can freely distribute this manual under the same condition, unmodified and without any material compensation.

## 8.5 Contact

Maximilien MOUSSET
max-mod@max-mod-shop.com
PM “MaX-MoD” on cnczone
PM “MaX-MoD” on usinages.com

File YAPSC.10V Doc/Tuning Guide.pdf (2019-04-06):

# YAPSC Tuning Tool

### PID Tuning Guide for YAPSC servo boards

## Abstract:

n this document you will see how to setup your YAPSC (V1 or 10V versions) Servomotor Controller using YTT.
This documents covers rapid description of YTT and PID tuning method using the step response tool of YTT.

I

YAPSC Tuning Tool – Tuning Guide Page 1/11

## Table Of Content

Page 2/11 YAPSC Tuning Tool – Tuning Guide

## 1 YTT description

YTT is ordered in three tabs: “Connection”, “Parameter” and “RT Monitor”.

## 1.1 “Connection” tab

In this tab, you can choose the serial port you want to use to connect to the YAPSC board; along with the model of the board. Currently you can choose between V1 and 10V versions.

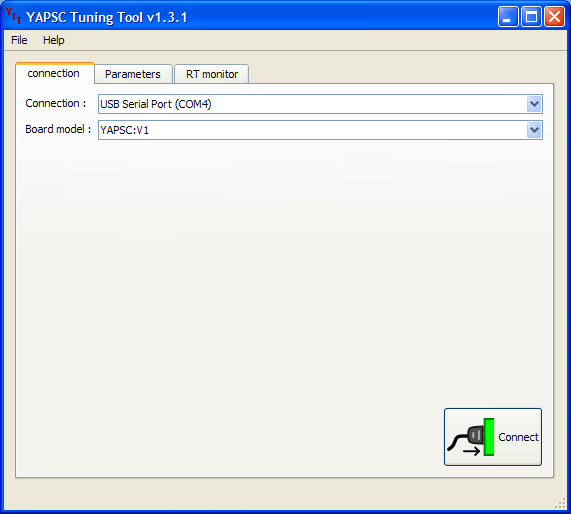
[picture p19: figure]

### Illustration 1.1: Connection Tab

Once the connection is established, you can use the two other tabs.

Note for the USB ProgKey users:
In the latest model, the ProgKey allows you to remotely reset the board. The board will be held in reset if you have not clicked on the “Connect” button. Once connection established, the blue LED of the ProgKey will turn dark (reset mode disabled). It can be really helpful during the first setup, while it's better to click the “Connect” button before plugging or unplugging the USB ProgKey onto a running YAPSC board: if held in reset mode, YAPSC will act as if completely unpowered.

## 1.2 “Parameters” tab

This tab displays all the parameters of the board. You will have a short description of each parameter if you hover it with your mouse.

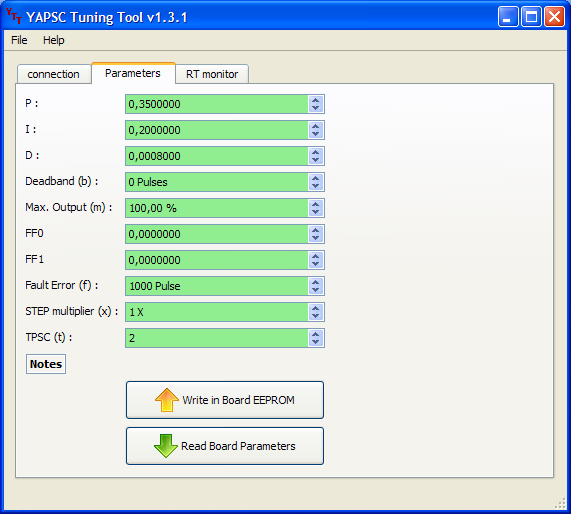
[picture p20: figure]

### Illustration 1.2: Parameters Tab

All parameters are either
- Green: parameter displayed is saved into the board
- orange: parameter displayed is different from the one saved into the board. Eg:

### Illustration 1.3: Modified parameters turn orange

P has been modified but is not saved in the board; while the displayed I and D values are the one saved in the board.

You have to save the parameters in the board (by clicking “Write in board EEPROM”) for the board to use the new value of the parameter.

You must start by reading the board parameters before writing them

## 1.3 “RT Monitor” tab

This tab gives you access to
- “Continuous sampling” tool: displays the boards' following error and output on the

Page 4/11 YAPSC Tuning Tool – Tuning Guide graph. Check the “Automatic” box and choose an update period to use.
- “Status” box: actual board's paramters
- board enabled
- following, integral and derivate error
- command & encoder feedback
- output level [-100; 100]
- “Step impulse response” box: this will be our most useful tool for PID tuning.

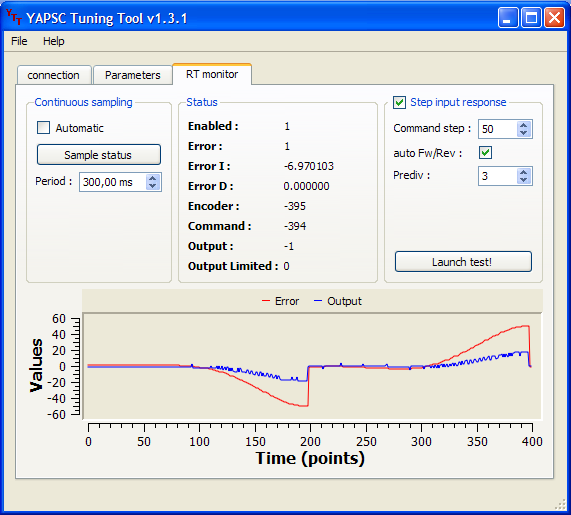
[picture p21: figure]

### Illustration 1.4: RT Monitor Tab

## 2 PID tuning: theory

From Wikipedia [link]: (http://en.wikipedia.org/wiki/PID_controller)
If the PID controller parameters (the gains of the proportional, integral and derivative terms) are chosen incorrectly, the controlled process input can be unstable, i.e. its output diverges, with or without oscillation, (http://en.wikipedia.org/wiki/Oscillation) and is limited only by saturation or mechanical breakage. Tuning a control loop is the adjustment of its control parameters (gain/proportional band, integral gain/reset, derivative gain/rate) to the optimum values for the desired control response.
(I advise that you read the whole article which is very well made if you want to know more about PID and closed loops in general.)
To sum up, we want the system to
- be stable
- be fast
- have no overshoot
These are the key to a well-tuned servomotor.

## 2.1 Common terms

- Error or Following Error: the difference of position (in encoder counts) between the actual motor's shaft position and the command
- Output : the command (voltage) applied on the motor. It's range is from -100% to 100% of the power supply voltage.
- Command : desired position for the motor's shaft (command by the computer to YAPSC board via STEP/DIR)
- Step input : when the command suddenly rises of a given value (eg: the command suddenly changes from 0 to +100)

## 2.2 Stability

First of all, you want your motor to go where you want him to go.
Here are, side by side, two things you want to avoid: divergence and oscillation

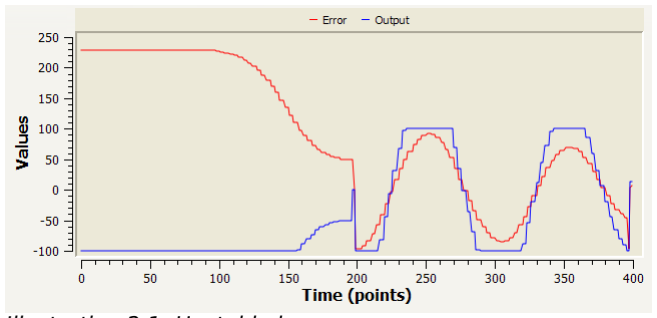
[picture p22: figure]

### Illustration 2.1: Unstable loops

- from points 1-200, we have a nice example of divergence: the motor polarity is wrong, so instead of bringing the motor back to the desired position, the control loop does the exact opposite! To fix that, you can
- Turn off the board, swap the motor's ends
- or use negative P, I, D coefficients
- From points 201-400 we can see a nice oscillation of the motor: P and/or I and/or D are set too high. Set I and D to 0 and decrease P until the loop stabilizes:

To avoid the motor from running at full speed until it crashed
your machine, don't forget to set up the “Fault Error” parameter! Typical values are in the 400-2000 counts.

Page 6/11 YAPSC Tuning Tool – Tuning Guide

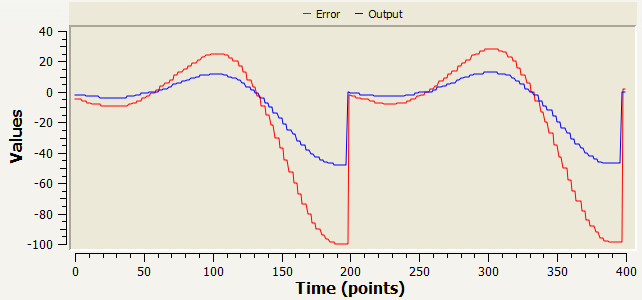
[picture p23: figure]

### Illustration 2.2: Stable loops

Now the loop is stable: the motor will follow (approximately) the command. It does not oscillate not it diverges.

## 2.3 Overshoot

Remember Ill. 7? Well we had a stable loop that follows more or less the command.
It does also show something we want to avoid: overshoot.
Overshoot is when the motor's shaft goes over the command. Here is, on the right overshot response curve and on the left a response curve with no overshoot:

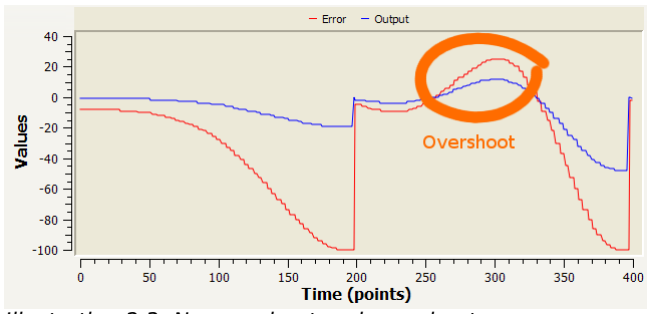
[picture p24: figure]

### Illustration 2.3: No-overshoot and overshoot

The error is negative at the beginning as actual position was below the command, but error goes over 0 (look at point 300) which means the motor position went over the command! The second curve (pts 1-200) shows no overshoot : error keeps the same sign (negative).

Q: Why is overshoot a bad thing?
A: Imagine you ask your CNC-milling machine to cut a 10mm long slot in some material. Because of overshoot, the slot may be 10.5mm long instead of 10mm. Ooops! The mill went too far!

## 3 PID tuning: application

## 3.1 Hardware setup

1. Let's start from the beginning:

Wire all the power supplies, STEP, DIR and ENABLE inputs.
After you have checked the wiring you can apply power. The ERR led should lit during approx ½ second at power-up.
2. If you have not installed YTT yet, it is time to do it. If you have never installed FTDI USB drivers before, check the last option to install the drivers.
3. Now, plug the Usb cable to the USB ProgKey. It should be recognized immediately.
4. Start YTT. In the “Connection” tab, check that “USB Serial Port (COMx)” is available, and choose it. If you have multiple of them, the progKey should be the latest of the list.
5. Click the “Connect” button, and pay attention to the ProgKey's blue LED: it should be dark. If not, you choose the wrong port number or the driver is not properly installed. You can try to restart your computer, it may help the first time you connect the ProgKey.
6. Now, you can plug the ProgKey on the 2*5pins header of the YAPSC board.
7. Go to “Parameter” tab and click “Read parameters” button. If all the parameters turn from gray to green, you have a working connection between your computer and YAPSC, congratulation!
8. Otherwise, try to disconnect and connect again (“Connection” tab). If it still does not work, verify your cabling with attention.
9. Now you have a working connection, you can move on the next step: testing!

## 3.2 PID Tuning

Do not forget that the "Step Impulse Response" test makes the motor move! In case of linear axis (example: X,Y and Z on a mill) turn the motor manually to reach the middle of the axis under testing before starting the test and setup the "Fault Error". Be sure to choose a command step small enough to avoid the carriage to crash on the ends of the slides.

First step for PID tuning is to set (roughly) the P parameter so we'll set I and D parameters to 0. The general method for loop tuning is to change one parameter at a time, run the test, analyze the response and start again until you cannot reduce the settling time anymore without loosing stability.

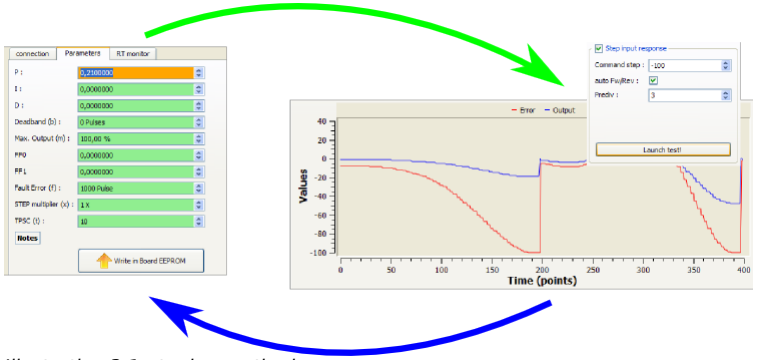
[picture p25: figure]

Page 8/11 YAPSC Tuning Tool – Tuning Guide

### Illustration 3.1 : tuning method

First, choose a command step amplitude. Something in the 50 – 100 range can give acceptable resolution. You can go higher, but an important thing is to keep (amplitude*P) < (Max Output/2). Otherwise the output is likely to saturate which will completely change the test results.

To calculate the equivalent move to the specified step, refer to section 5 Extra information.

### 3.2.1 P tuning

Augment progressively the P parameter until you get get no or little overshoot. A nice curve would be between the "no overshoot" and "overshoot" example of Illustration 2.3: No-overshoot and overshoot.
At this point, it is not a problem if there is little overshoot. The D parameter reduces efficiently the overshoot.

### 3.2.2 I tuning

Most of time, P gain tuning alone cannot make the motor reach exactly the goal; there is a static error. For example, you ask for a 50 steps move and the motor stops after 46 steps: the static error is 4.
Augment I parameter until the static error reaches 0, but while keeping loop stability

### 3.2.3 D tuning

The D parameter should be used to erase eventual overshoot but don't set it too high as it will reduce the response time.

### 3.2.4 Sum up

To Improve... | Action on P | Action on I | Action on D
...Response time | increase | increase | decrease
...Stability | decrease | decrease | increase
...Precision | Increase (decrease if not stable) | increase | -

## 4 Troubleshooting

Here are the common problems you may face.

## 4.1 Inverted polarity

Problem description: as soon as the motor moves a bit it runs into the same direction and the boards goes in "Maxerror Fault".
Fix: The fix is simple. You can swap A and B encoder inputs OR use negative PID parameters (example: P=-0.23; I=-0.07; D=-0.016)

## 5 Extra information

## 5.1 From steps to rev

To calculate the equivalent in revolutions to steps step move use this formula:

### rev=

### steps PPR×4

PPR is the Pulse Per Revolution of the encoder. Can be called the number of lines of the encoder. (ex: "500 lines encoder" has PPR=500)

## 5.2 From steps to mm (in)

For a l lead screw driven by m:n reduction, steps step move is equivalent to:

=

m×l
n

### ×rev

Example for a 5mm/turn (5mm lead) ballscrew driven by our motor through a 1:3 reduction: a 50 steps move is
1×5
3

×

### steps PPR×4

=

5
3

×

50
500×4

=0,042 mm

The encoder PPR is 500.

## 5.3 Units per Step

It represents of how much the machine moves for each step.

### UpS=

m×l

### n×PPR×4

This is commonly used by your fab soft (MAC3/EMC etc).

Page 10/11 YAPSC Tuning Tool – Tuning Guide

## Document Revisions

Rev | Date | Description
1 | 11/22/09 | First version of this manual

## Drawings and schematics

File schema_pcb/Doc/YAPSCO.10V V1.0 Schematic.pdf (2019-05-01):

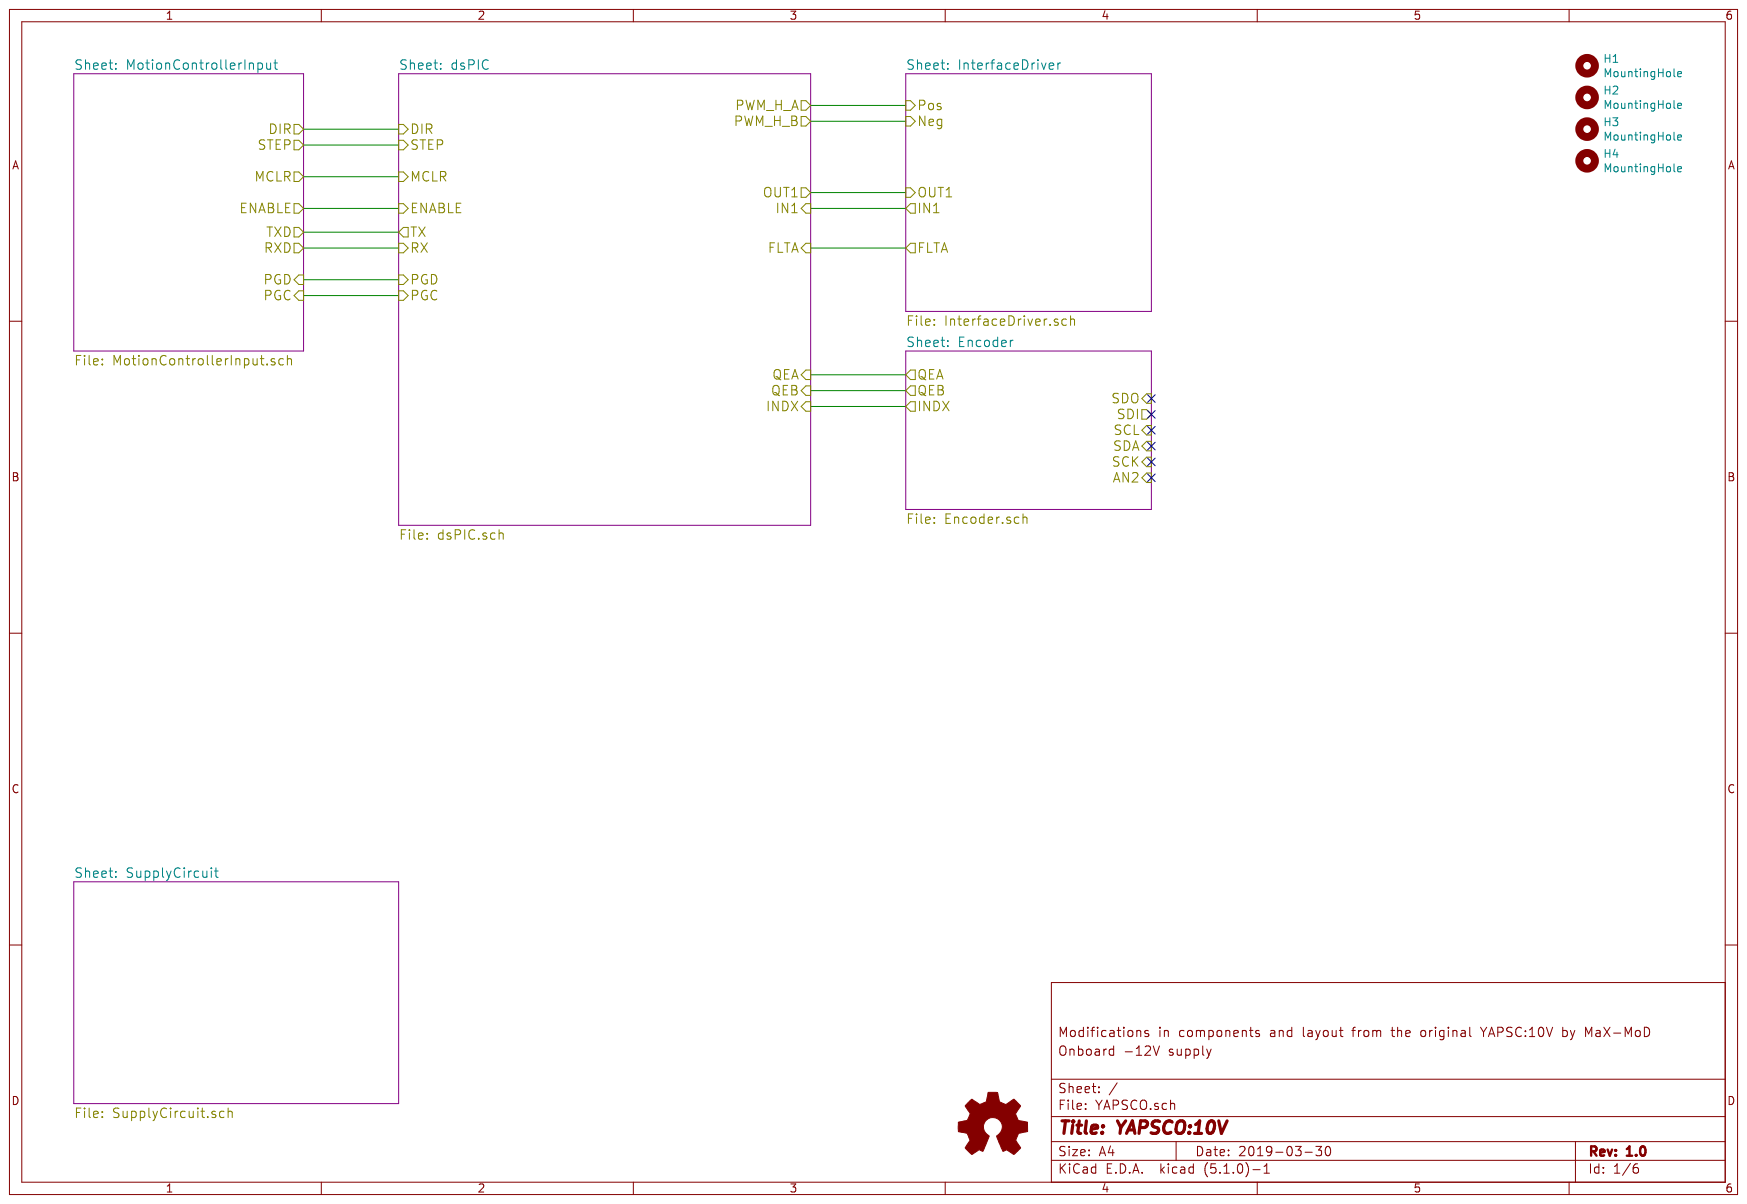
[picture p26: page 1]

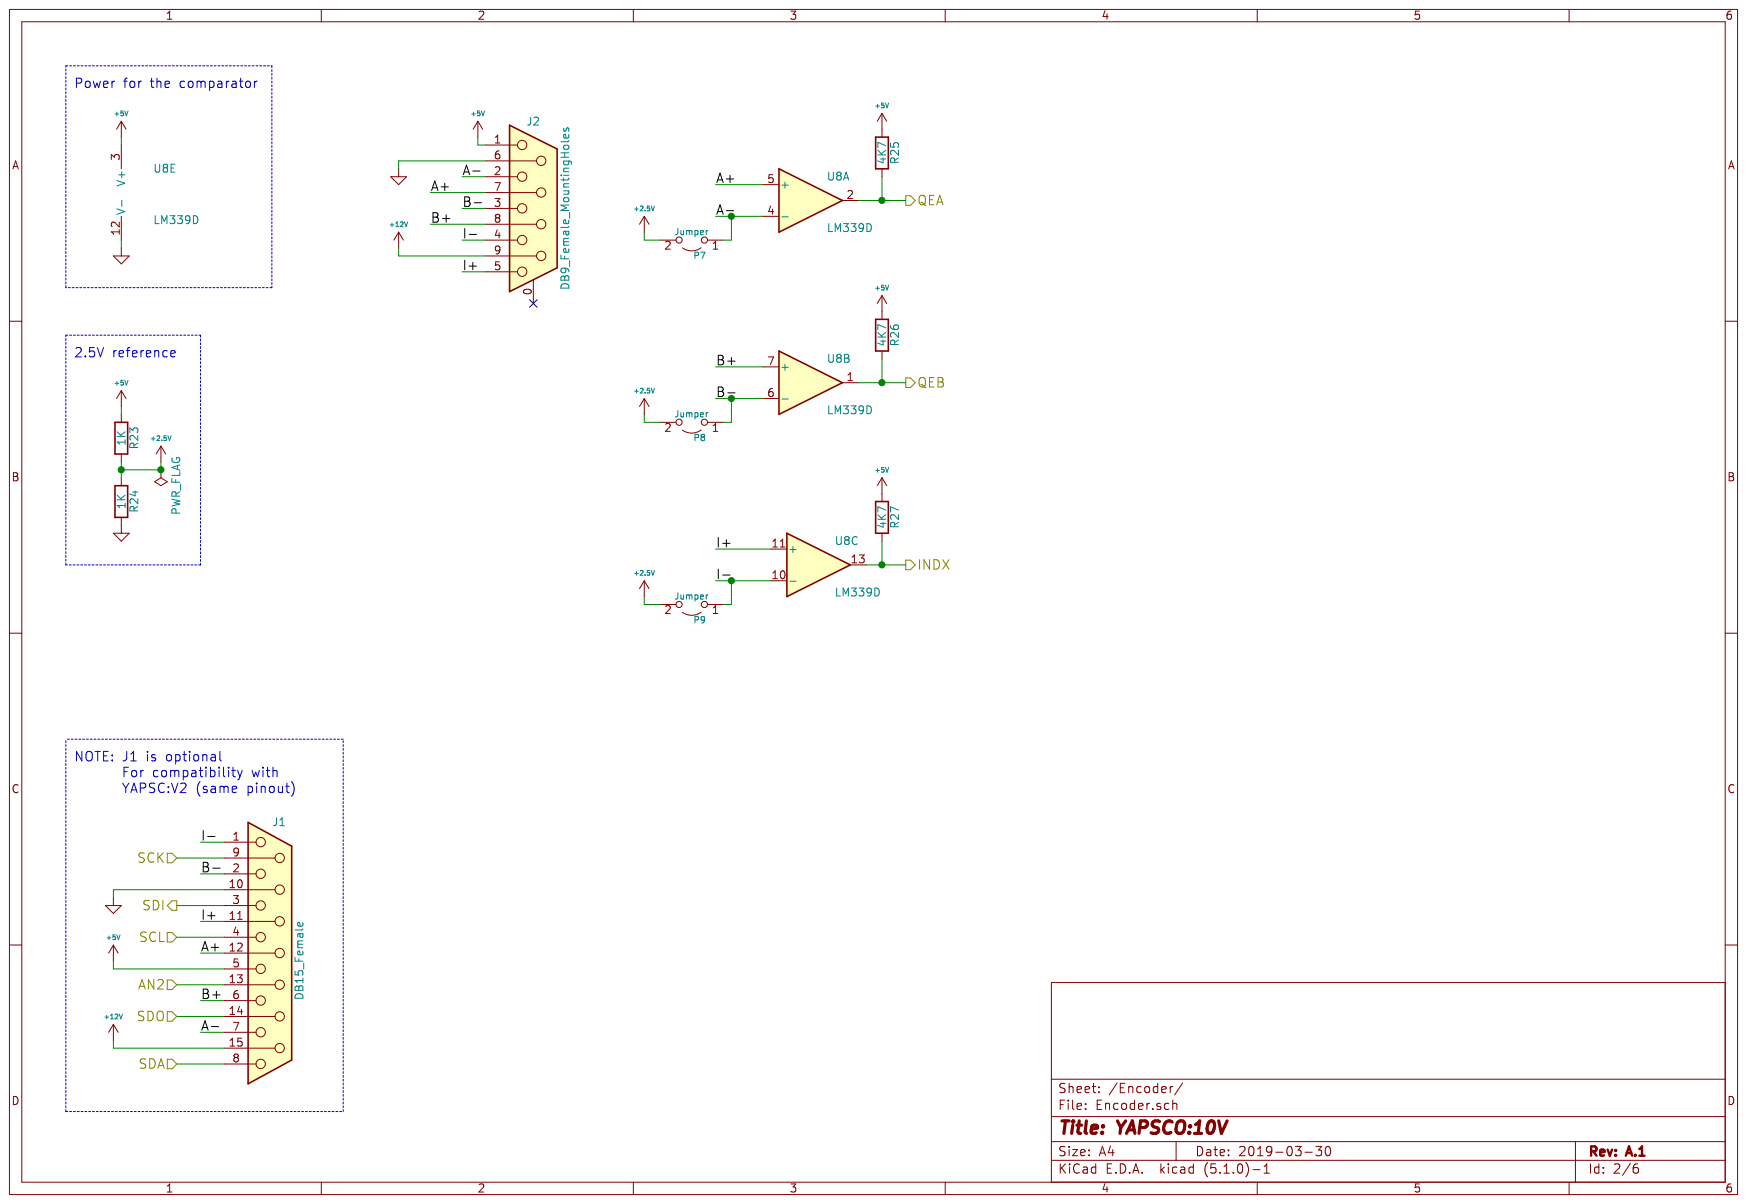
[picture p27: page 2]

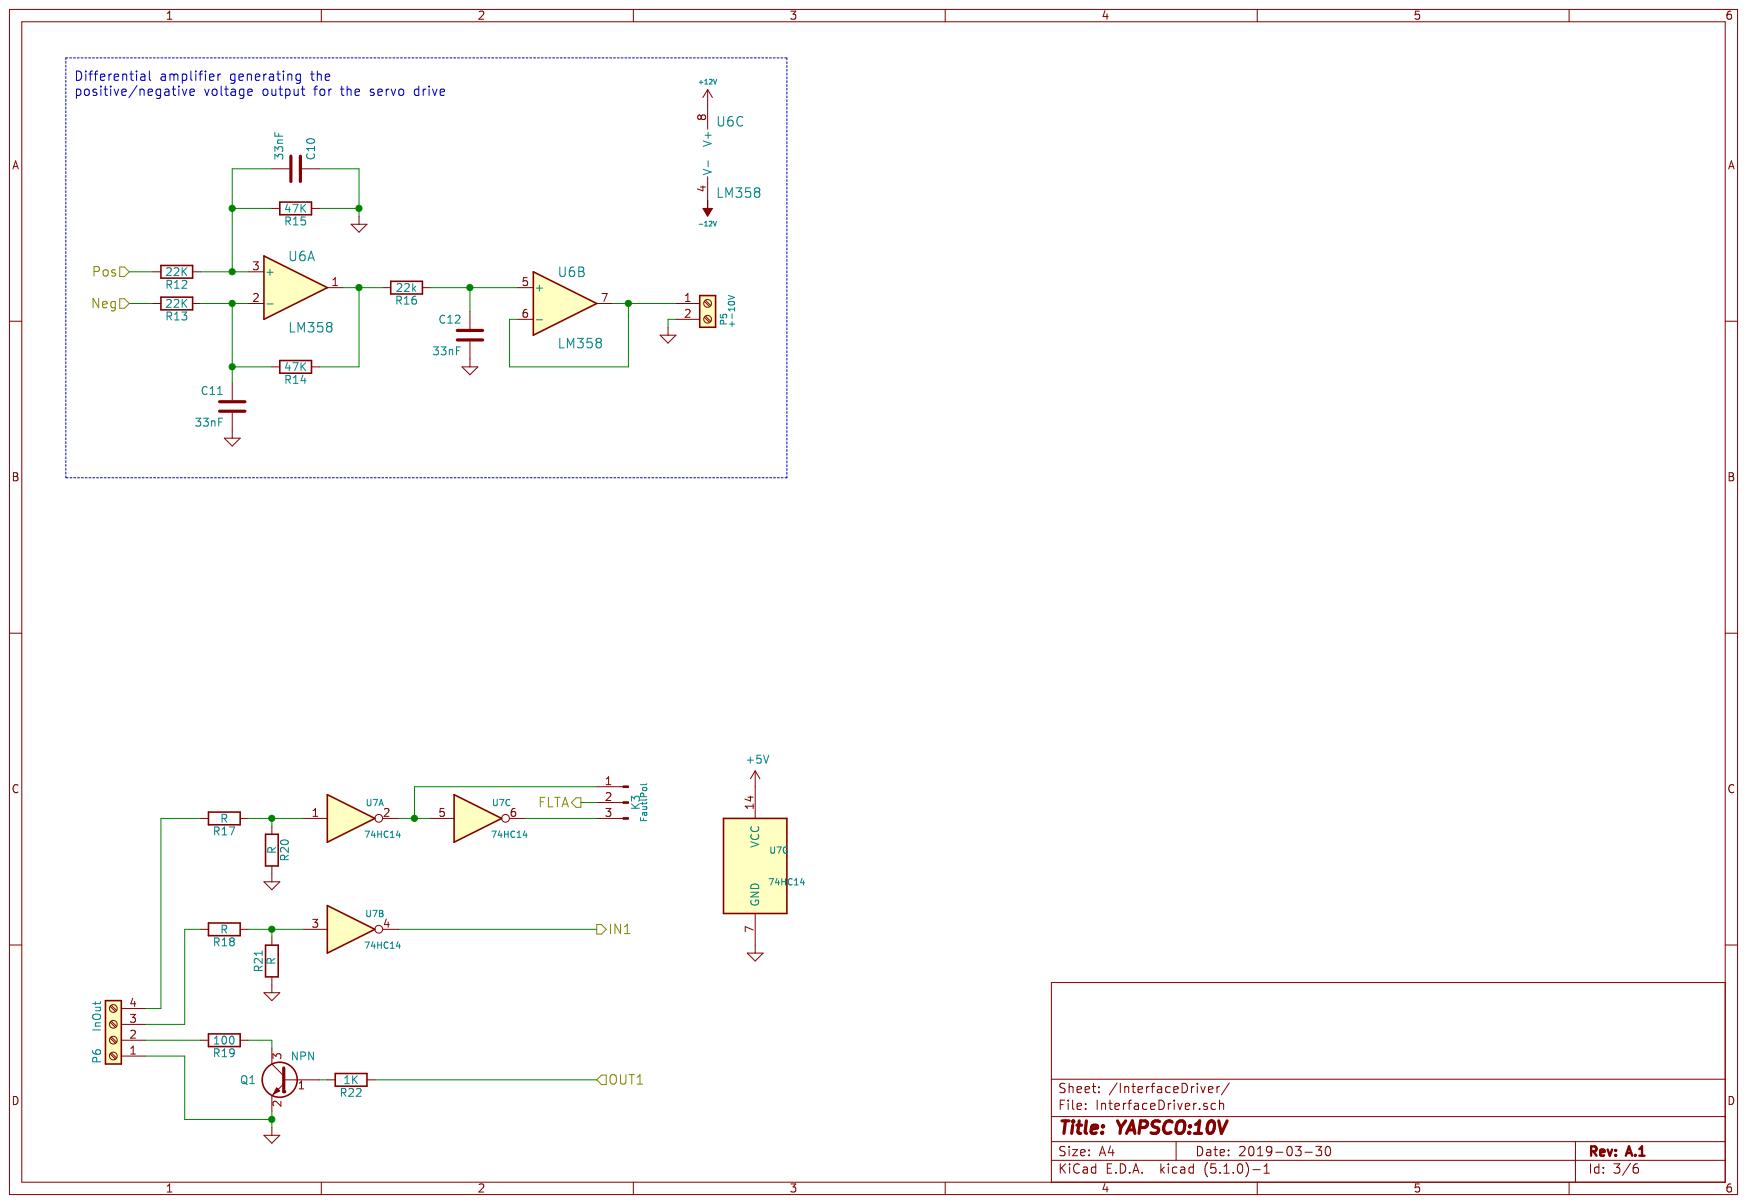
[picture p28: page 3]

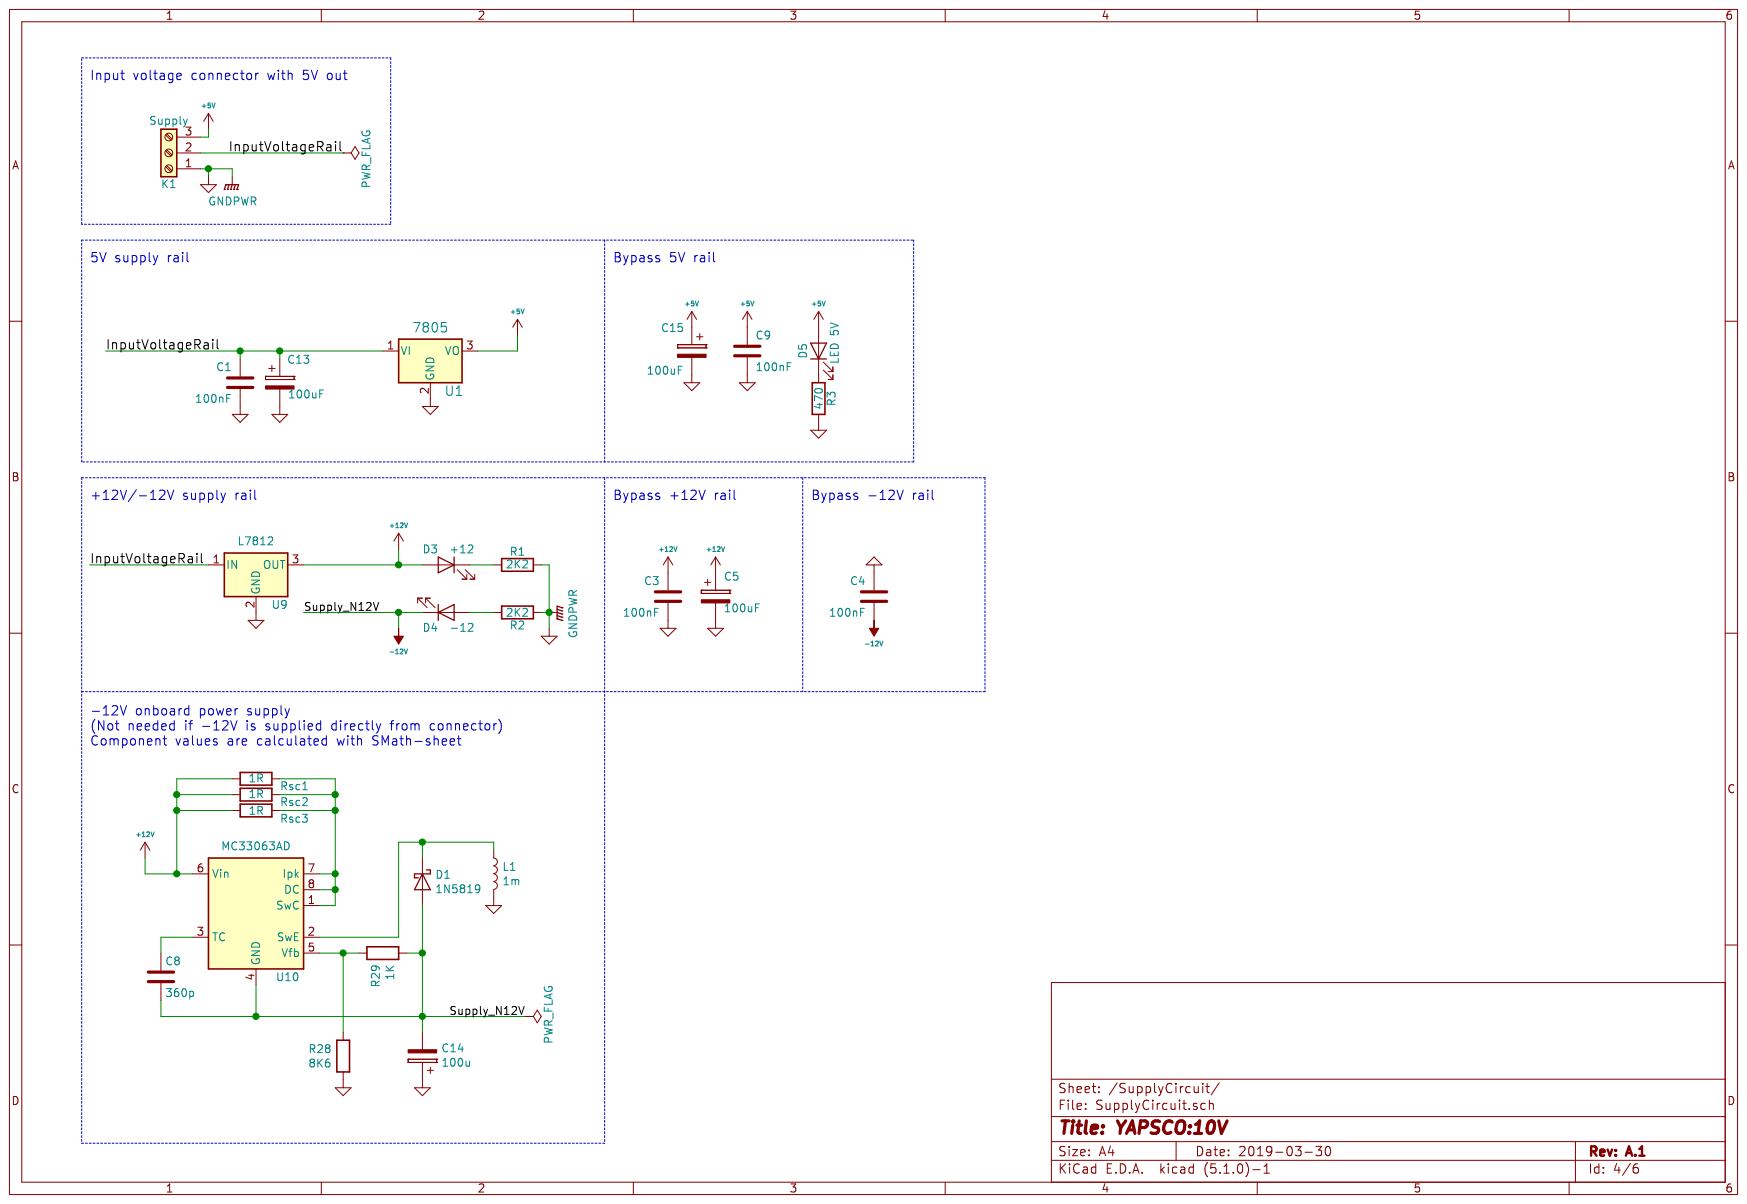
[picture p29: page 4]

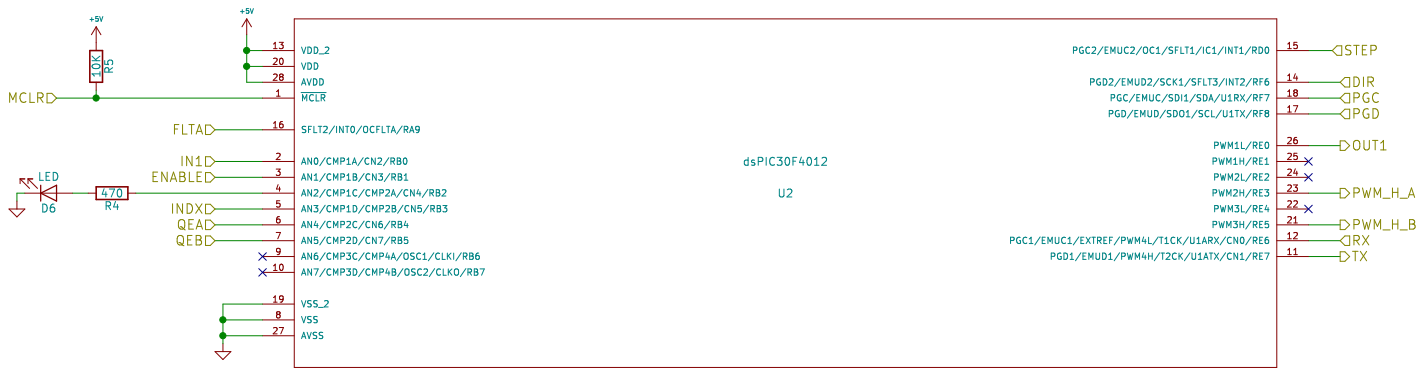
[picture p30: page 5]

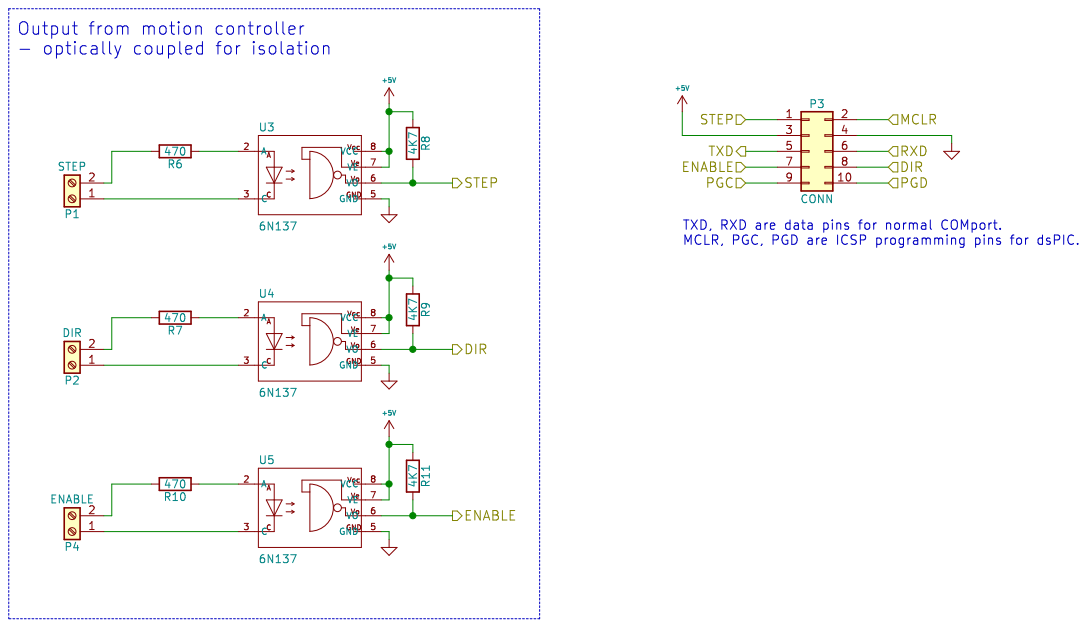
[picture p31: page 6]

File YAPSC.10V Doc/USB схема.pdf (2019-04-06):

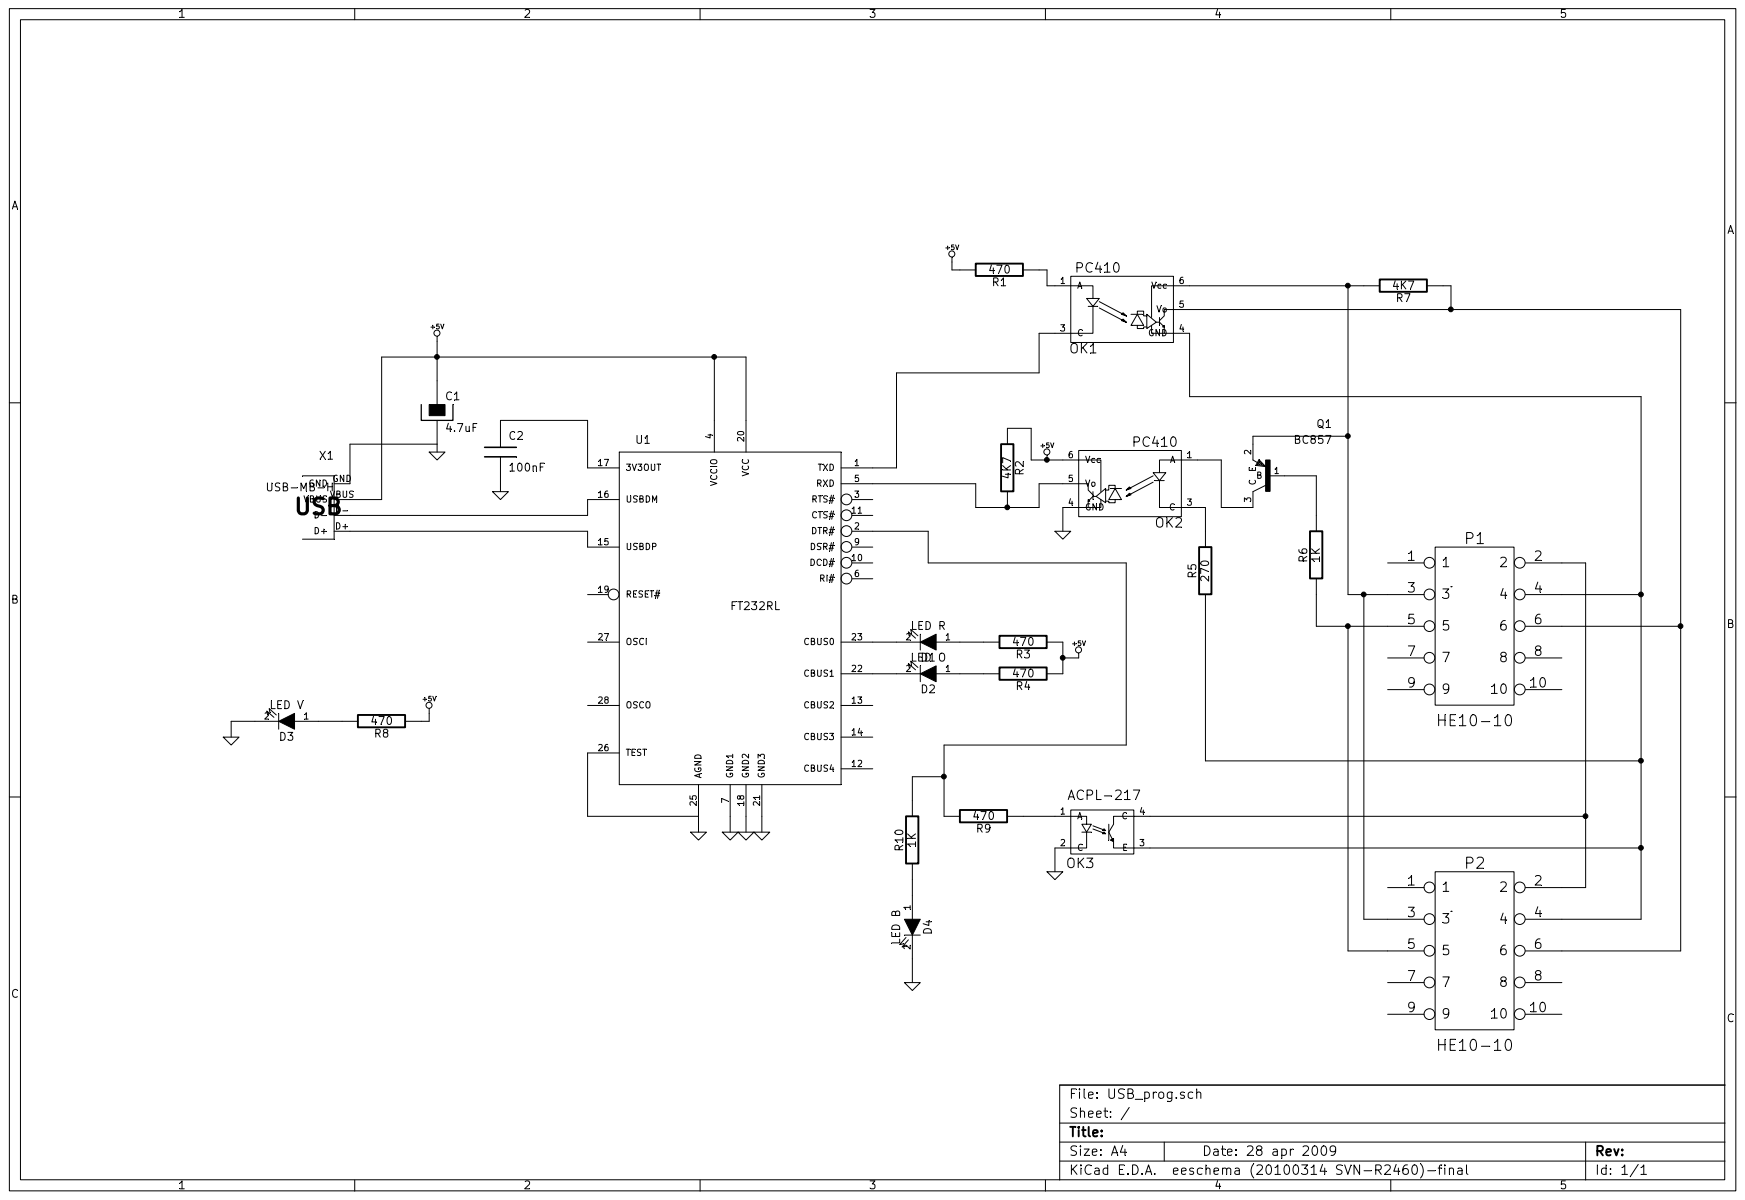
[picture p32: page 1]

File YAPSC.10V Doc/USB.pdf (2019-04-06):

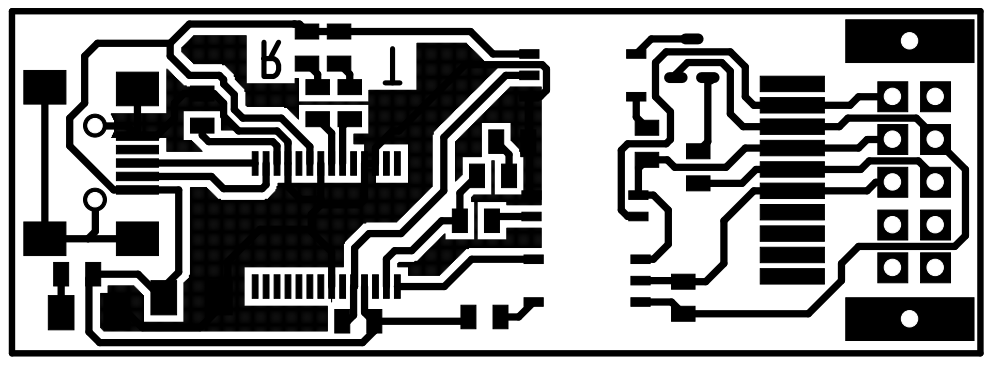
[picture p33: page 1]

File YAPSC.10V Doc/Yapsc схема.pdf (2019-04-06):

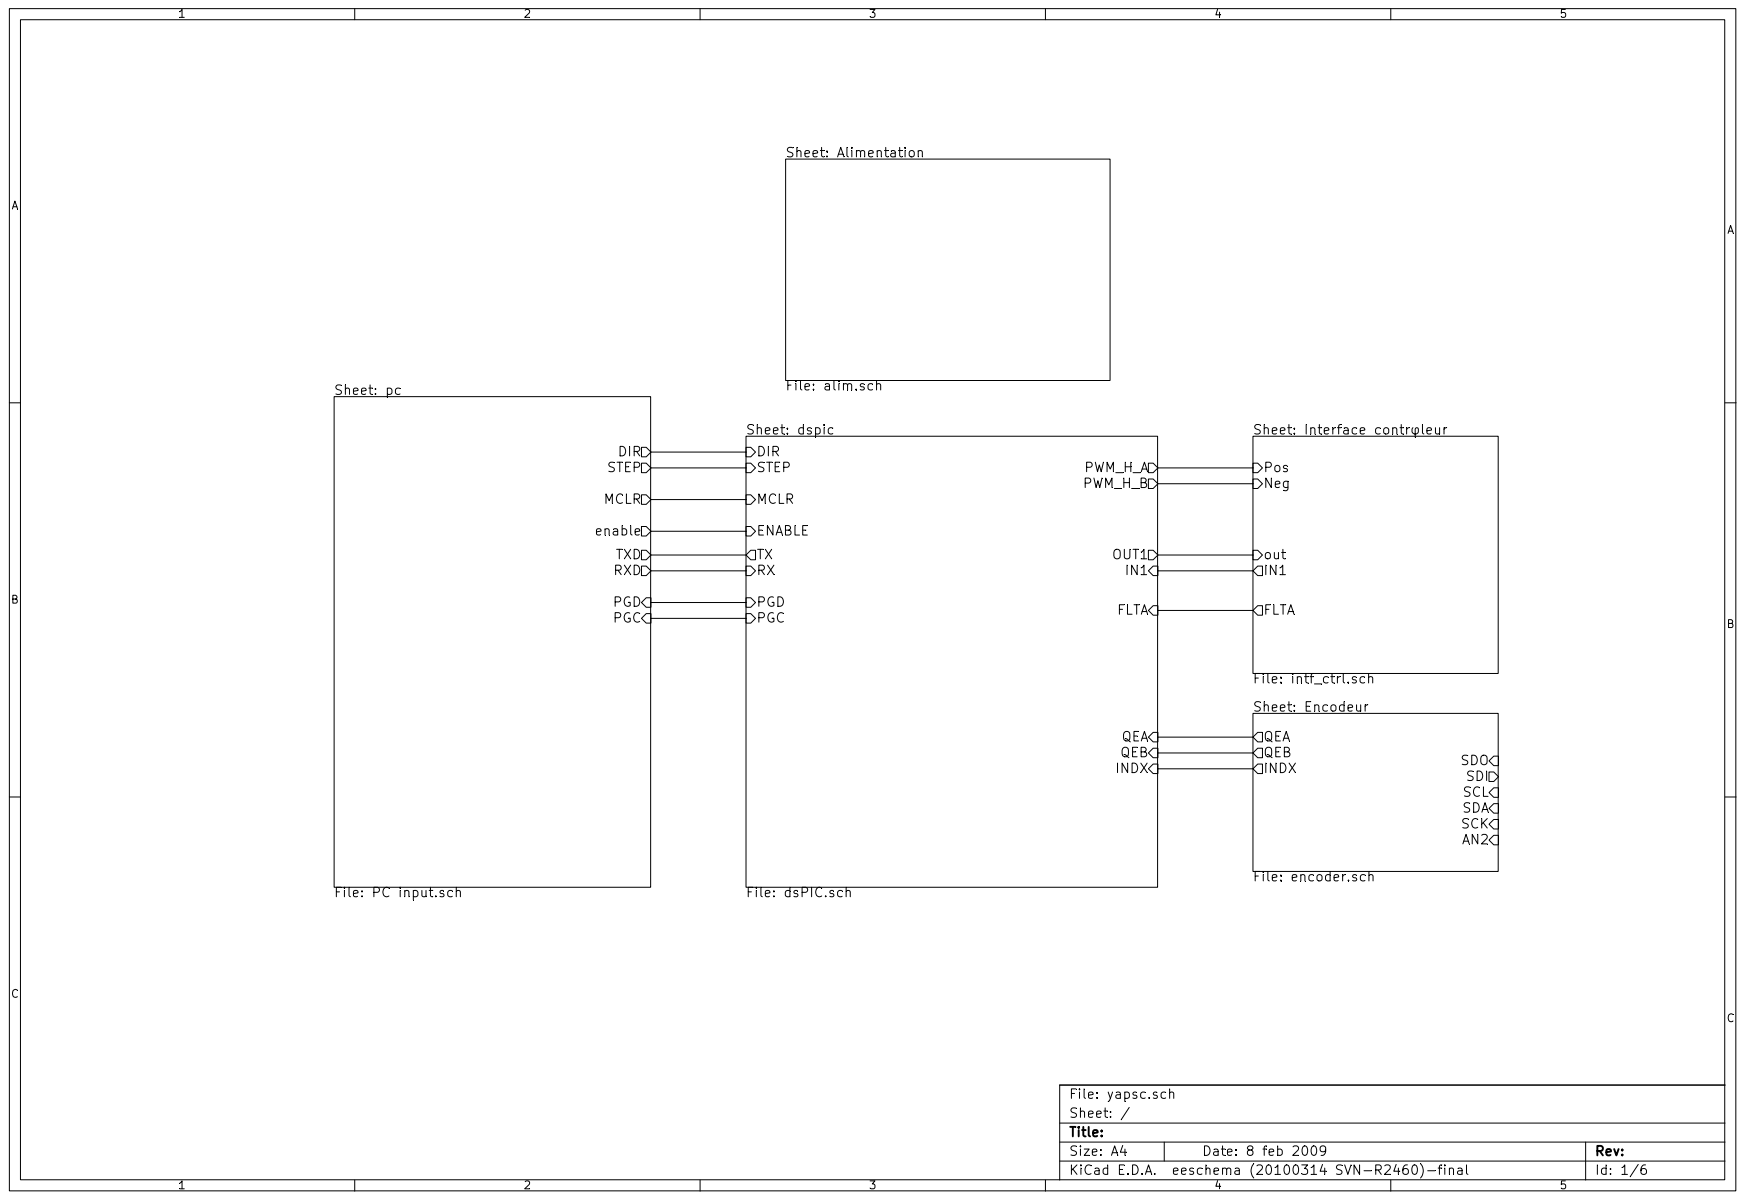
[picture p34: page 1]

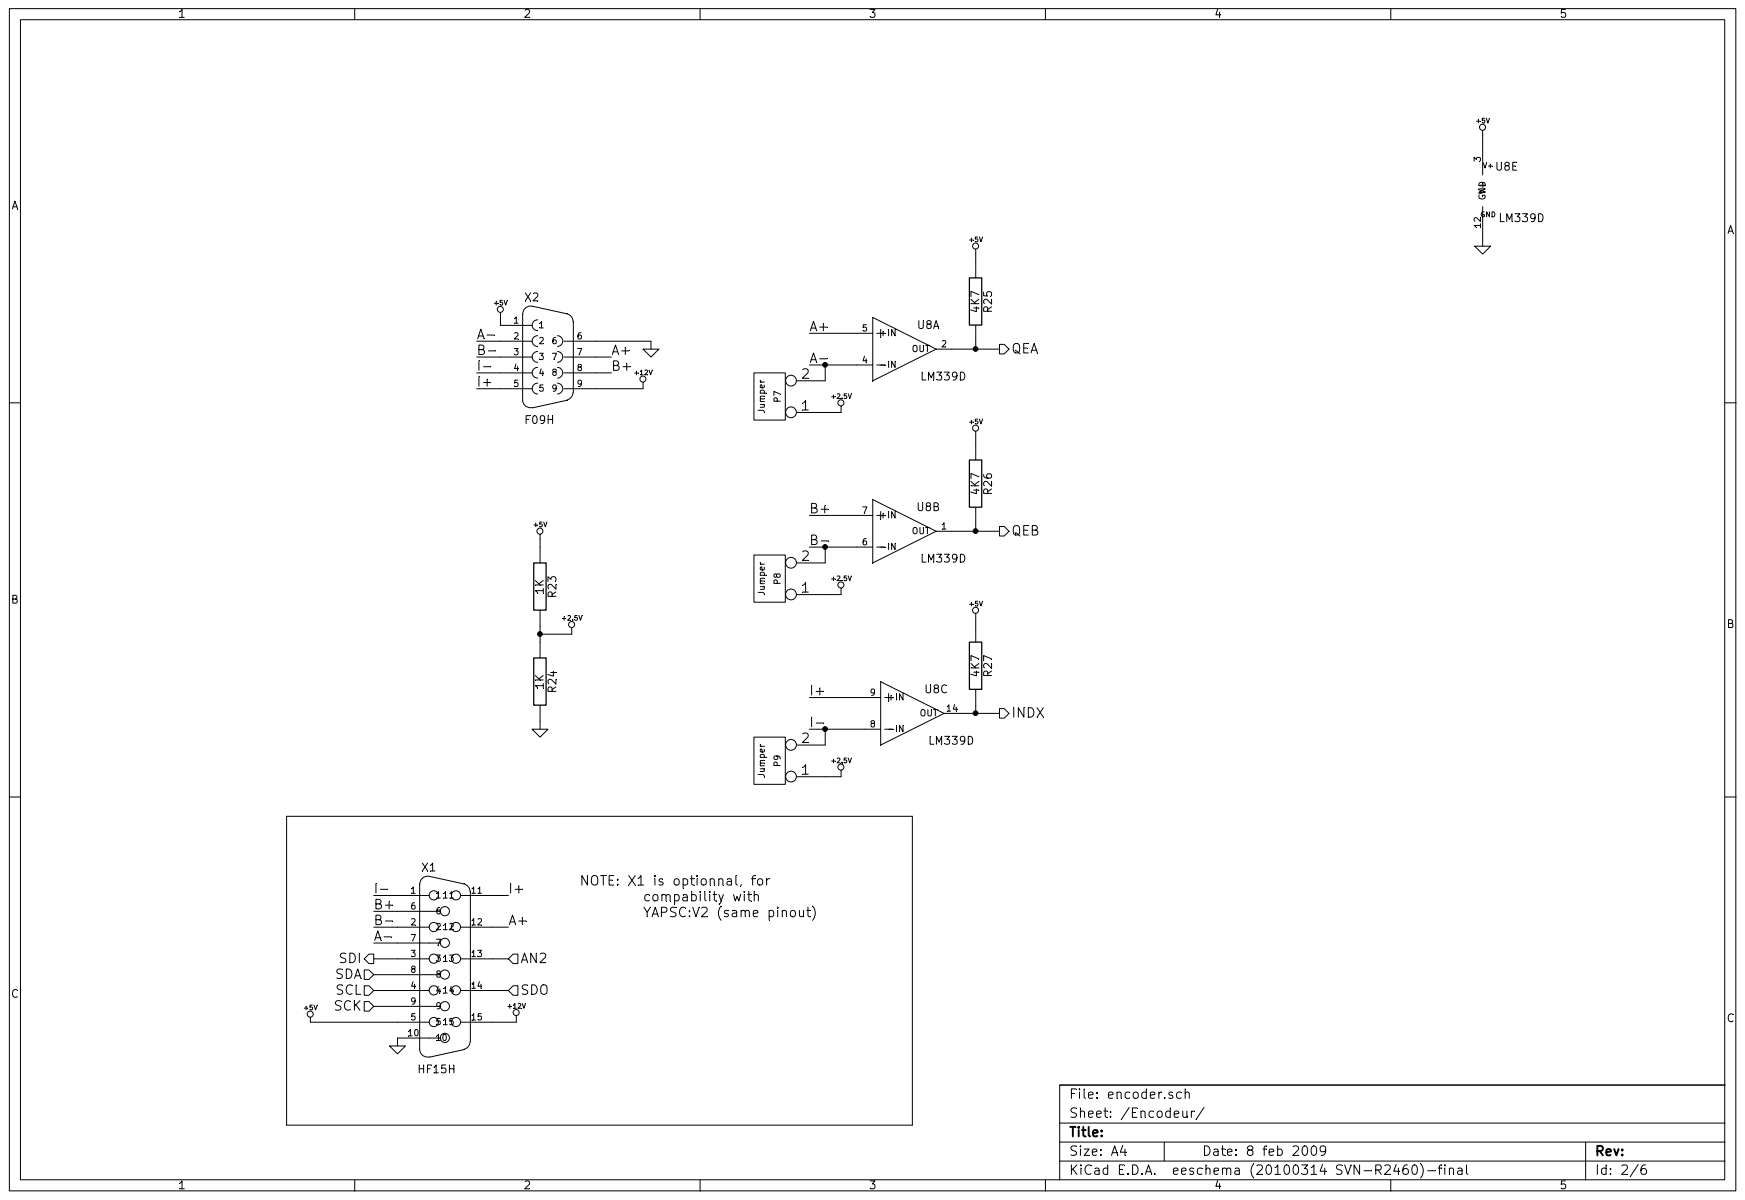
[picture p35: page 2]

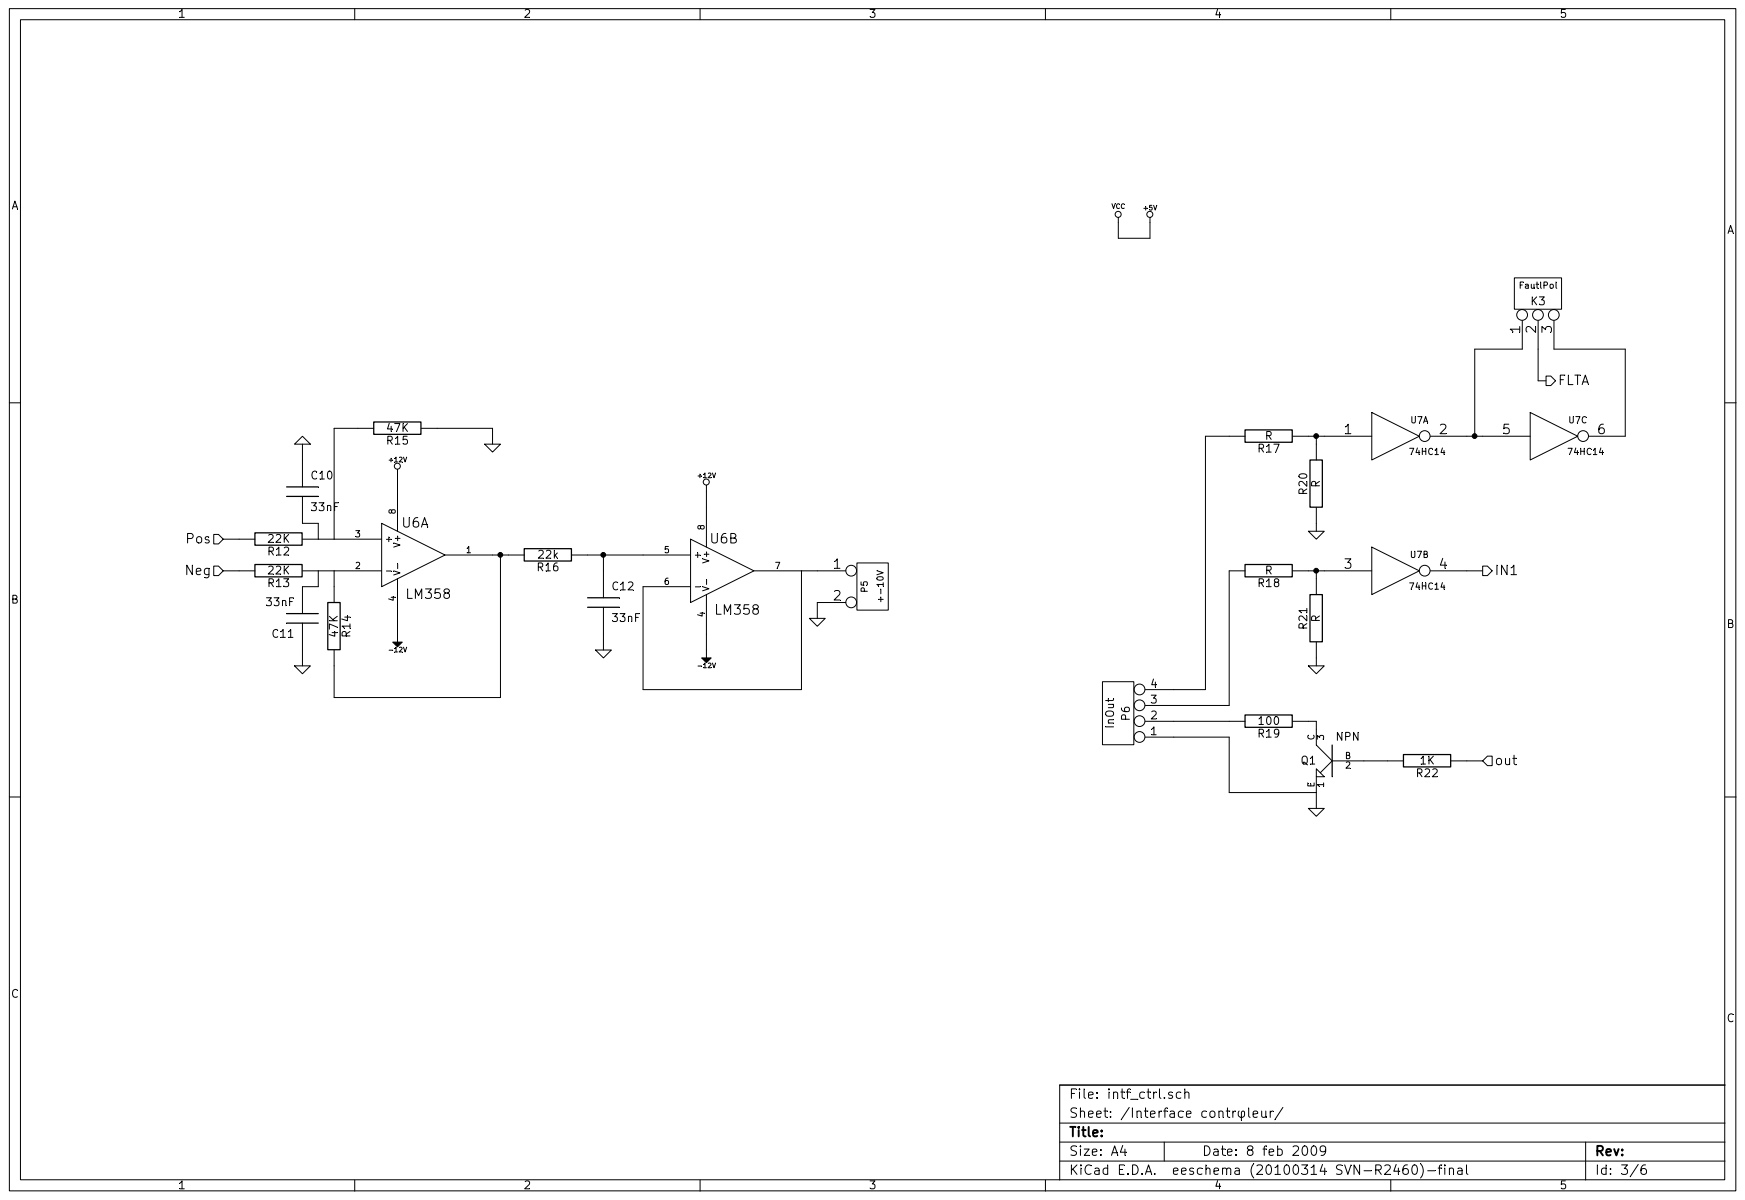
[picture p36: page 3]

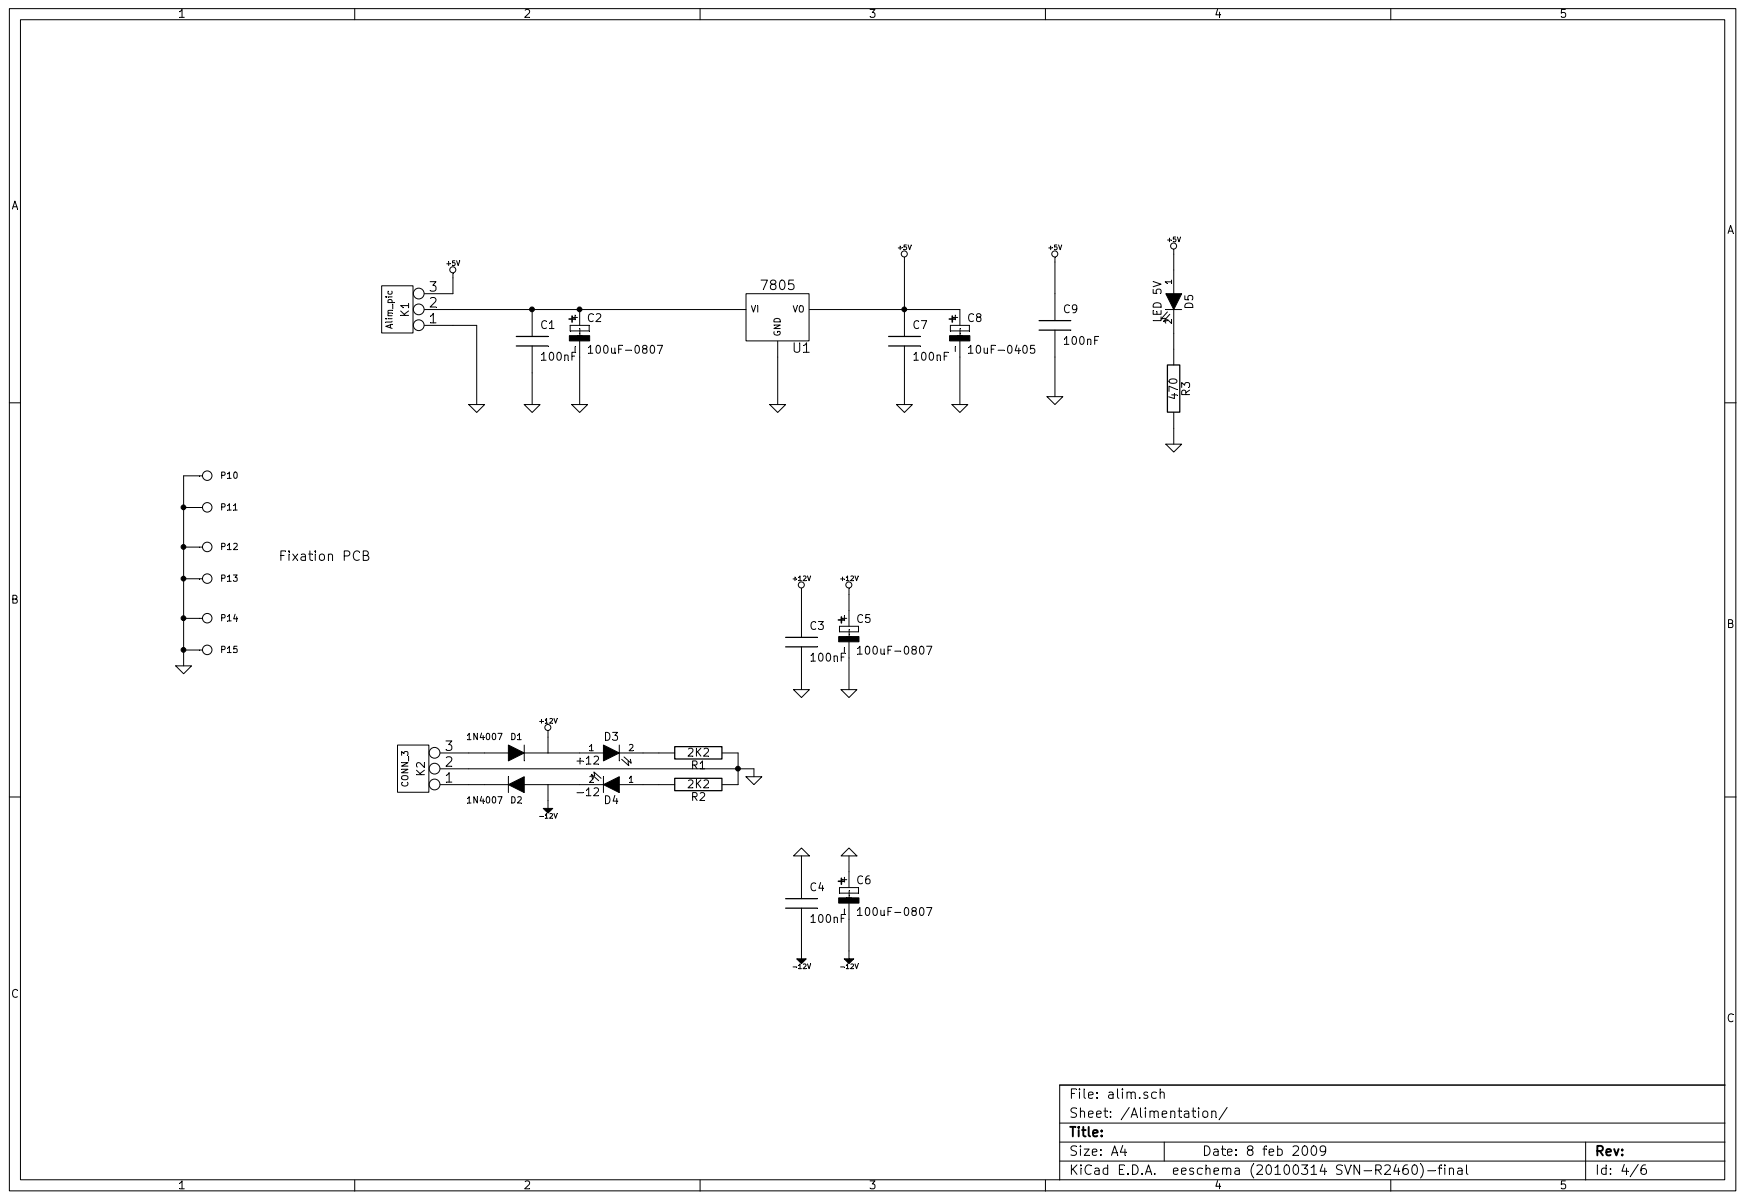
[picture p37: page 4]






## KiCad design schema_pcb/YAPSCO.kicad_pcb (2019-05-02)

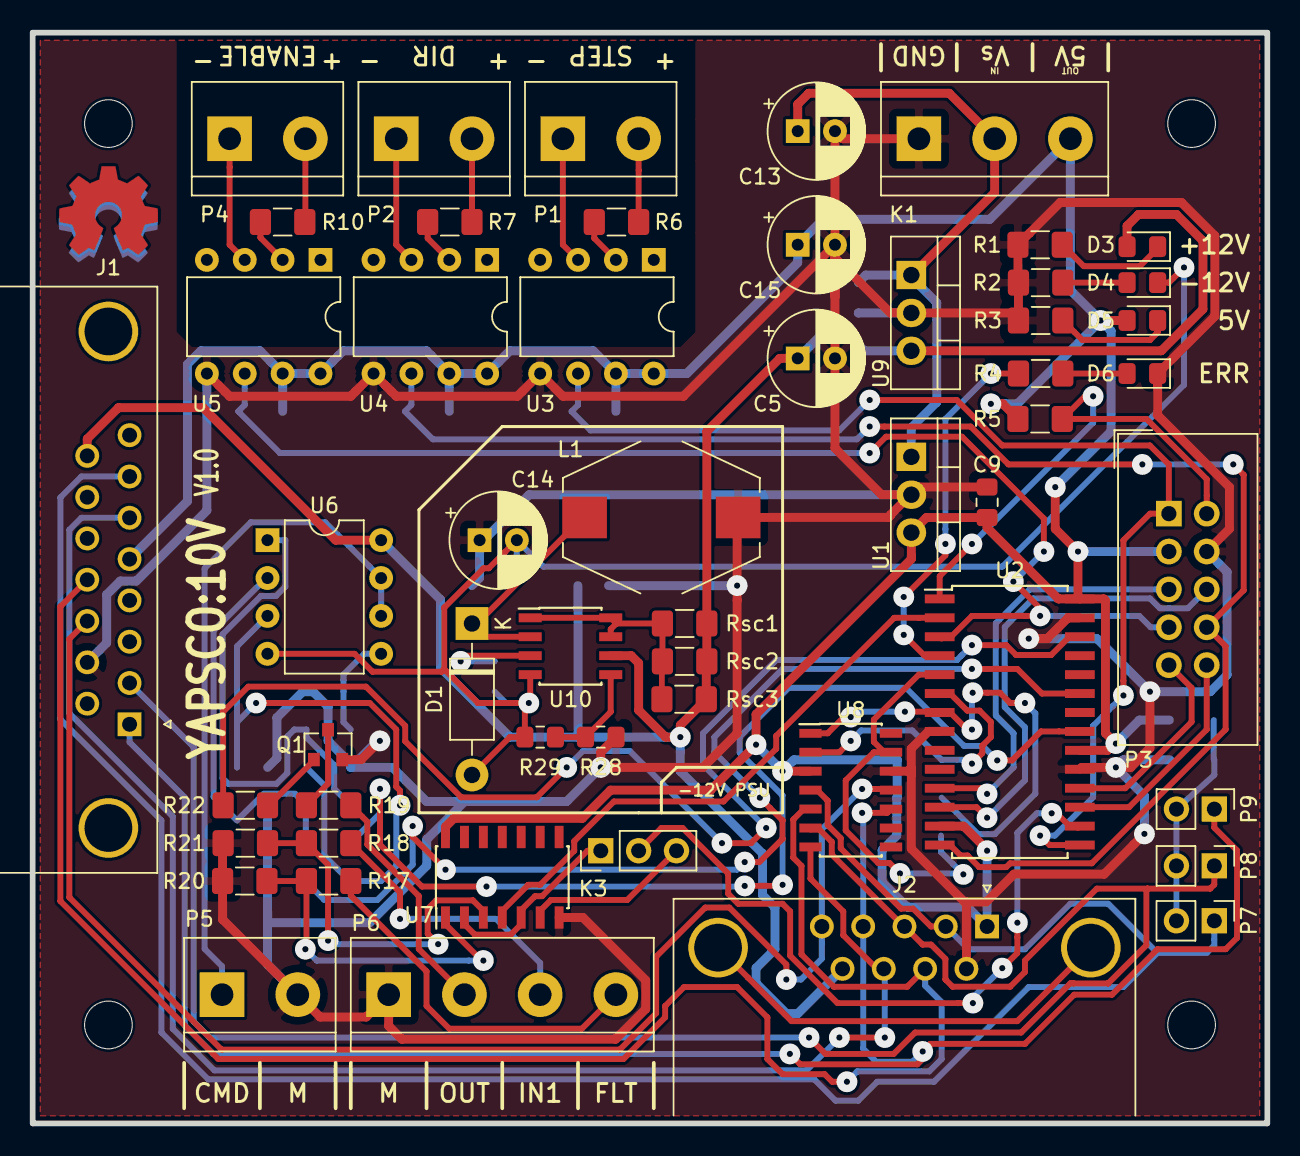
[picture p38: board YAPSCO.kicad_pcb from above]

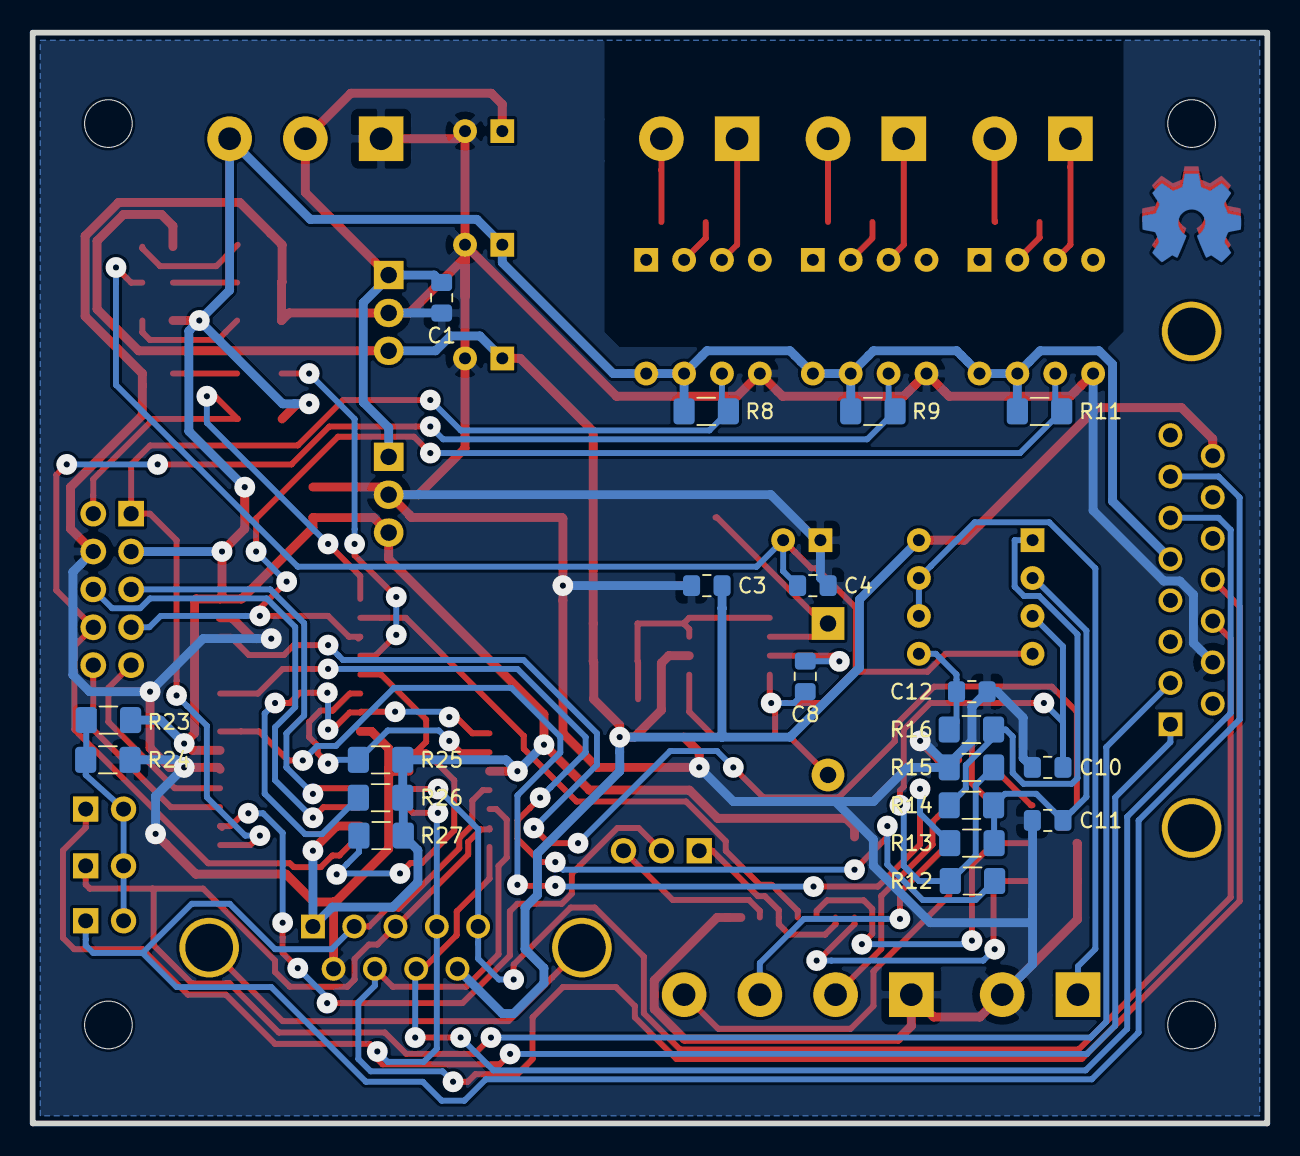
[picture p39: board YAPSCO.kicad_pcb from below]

Board: 2 copper layers, 82.8 x 73.2 mm, 78 parts (20 on the bottom side), 60 nets.

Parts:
C1, C3, C4, C9: 100nF; C_0805_2012Metric_Pad1.15x1.40mm_HandSolder
C5, C13, C15: 100uF; CP_Radial_D6.3mm_P2.50mm
C8: 360p; C_0805_2012Metric_Pad1.15x1.40mm_HandSolder
C10, C11, C12: 33nF; C_0805_2012Metric_Pad1.15x1.40mm_HandSolder
C14: 100u; CP_Radial_D6.3mm_P2.50mm
D1: 1N5819; D_DO-41_SOD81_P10.16mm_Horizontal
D3: +12; D_0805_2012Metric_Pad1.15x1.40mm_HandSolder
D4: -12; D_0805_2012Metric_Pad1.15x1.40mm_HandSolder
D5: LED 5V; LED_0805_2012Metric_Pad1.15x1.40mm_HandSolder
D6: LED; LED_0805_2012Metric_Pad1.15x1.40mm_HandSolder
H1, H2, H3, H4: MountingHole; MountingHole_3.2mm_M3_ISO7380
J1: DB15_Female; DSUB-15_Female_Horizontal_P2.77x2.84mm_EdgePinOffset9.90mm_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
J2: DB9_Female_MountingHoles; DSUB-9_Female_Horizontal_P2.77x2.84mm_EdgePinOffset9.90mm_H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
K1: Supply; TerminalBlock_bornier-3_P5.08mm
K3: FautlPol; PinHeader_1x03_P2.54mm_Vertical
L1: 1m; L_Bourns-SRR1005
P1: STEP; TerminalBlock_bornier-2_P5.08mm
P2: DIR; TerminalBlock_bornier-2_P5.08mm
P3: CONN; IDC-Header_2x05_P2.54mm_Vertical
P4: ENABLE; TerminalBlock_bornier-2_P5.08mm
P5: +-10V; TerminalBlock_bornier-2_P5.08mm
P6: InOut; TerminalBlock_bornier-4_P5.08mm
P7, P8, P9: Jumper; PinHeader_1x02_P2.54mm_Vertical
Q1: NPN; SOT-23
R1, R2: 2K2; R_1206_3216Metric_Pad1.42x1.75mm_HandSolder
R3, R4, R6, R7, R10: 470; R_1206_3216Metric_Pad1.42x1.75mm_HandSolder
R5: 10K; R_1206_3216Metric_Pad1.42x1.75mm_HandSolder
R8, R9, R11, R25, R26, R27: 4K7; R_1206_3216Metric_Pad1.42x1.75mm_HandSolder
R12, R13: 22K; R_1206_3216Metric_Pad1.42x1.75mm_HandSolder
R14, R15: 47K; R_1206_3216Metric_Pad1.42x1.75mm_HandSolder
R16: 22k; R_1206_3216Metric_Pad1.42x1.75mm_HandSolder
R17, R18, R20, R21: R; R_1206_3216Metric_Pad1.42x1.75mm_HandSolder
R19: 100; R_1206_3216Metric_Pad1.42x1.75mm_HandSolder
R22, R23, R24: 1K; R_1206_3216Metric_Pad1.42x1.75mm_HandSolder
R28: 8K6; R_0805_2012Metric_Pad1.15x1.40mm_HandSolder
R29: 1K; R_0805_2012Metric_Pad1.15x1.40mm_HandSolder
Rsc1, Rsc2, Rsc3: 1R; R_1206_3216Metric_Pad1.42x1.75mm_HandSolder
U1: 7805; TO-220-3_Vertical
U2: dsPIC30F4012; SOIC-28W_7.5x17.9mm_P1.27mm
U3, U4, U5: 6N137; DIP-8_W7.62mm
U6: LM358; DIP-8_W7.62mm
U7: 74HC14; SOIC-14_3.9x8.7mm_P1.27mm
U8: LM339D; SOIC-14_3.9x8.7mm_P1.27mm
U9: L7812; TO-220-3_Vertical
U10: MC33063AD; SOIC-8_3.9x4.9mm_P1.27mm

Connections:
+2V5: P7.2, P8.2, P9.2, R23.2, R24.1
+5V: C9.1, C15.1, D5.2, J1.5, J2.1, K1.3, P3.3, R5.1, R8.1, R9.1, R11.1, R23.1, R25.1, R26.1, R27.1, U1.3, U2.13, U2.20, U2.28, U3.7, U3.8, U4.7, U4.8, U5.7, U5.8, U7.14, U8.3
+12V: C3.1, C5.1, D3.2, J1.15, J2.9, Rsc1.2, Rsc2.2, Rsc3.2, U6.8, U9.3, U10.6
-12V: C4.2, C8.2, C14.2, D1.2, D4.1, R29.2, U6.4, U10.4
/Encoder/A+: J1.12, J2.7, U8.5
/Encoder/A-: J1.7, J2.2, P7.1, U8.4
/Encoder/B+: J1.6, J2.8, U8.7
/Encoder/B-: J1.2, J2.3, P8.1, U8.6
/Encoder/I+: J1.11, J2.5, U8.11
/Encoder/I-: J1.1, J2.4, P9.1, U8.10
/Encoder/INDX: R27.2, U2.5, U8.13
/Encoder/QEA: R25.2, U2.6, U8.2
/Encoder/QEB: R26.2, U2.7, U8.1
/InterfaceDriver/FLTA: K3.2, U2.16
/InterfaceDriver/IN1: U2.2, U7.4
/InterfaceDriver/Neg: R13.2, U2.21
/InterfaceDriver/OUT1: R22.1, U2.26
/MotionControllerInput/DIR: P3.8, R9.2, U2.14, U4.6
/MotionControllerInput/ENABLE: P3.7, R11.2, U2.3, U5.6
/MotionControllerInput/MCLR: P3.2, R5.2, U2.1
/MotionControllerInput/PGC: P3.9, U2.18
/MotionControllerInput/PGD: P3.10, U2.17
/MotionControllerInput/STEP: P3.1, R8.2, U2.15, U3.6
/SupplyCircuit/InputVoltageRail: C1.1, C13.1, K1.2, U1.1, U9.1
/dsPIC/PWM_H_A: R12.2, U2.23
/dsPIC/RX: P3.6, U2.12
/dsPIC/TX: P3.5, U2.11
GND: C1.2, C3.2, C4.1, C5.2, C9.2, C10.1, C11.2, C12.2, C13.2, C14.1, C15.2, D6.1, J1.10, J2.6, K1.1, L1.2, P3.4, P5.2, P6.1, Q1.2, R1.1, R2.1, R3.2, R15.1, R20.1, R21.1, R24.2, R28.2, U1.2, U2.8, U2.19, U2.27, U3.5, U4.5, U5.5, U7.7, U8.12, U9.2
unnamed: C8.1, U10.3
unnamed: C10.2, R12.1, R15.2, U6.3
unnamed: C11.1, R13.1, R14.2, U6.2
unnamed: C12.1, R16.1, U6.5
unnamed: D1.1, L1.1, U10.2
unnamed: D3.1, R1.2
unnamed: D4.2, R2.2
unnamed: D5.1, R3.1
unnamed: D6.2, R4.2
unnamed: K3.1, U7.2, U7.5
unnamed: K3.3, U7.6
unnamed: P1.1, U3.3
unnamed: P1.2, R6.2
unnamed: P2.1, U4.3
unnamed: P2.2, R7.2
unnamed: P4.1, U5.3
unnamed: P4.2, R10.2
unnamed: P5.1, U6.6, U6.7
unnamed: P6.2, R19.2
unnamed: P6.3, R18.2
unnamed: P6.4, R17.2
unnamed: Q1.1, R22.2
unnamed: Q1.3, R19.1
unnamed: R4.1, U2.4
unnamed: R6.1, U3.2
unnamed: R7.1, U4.2
unnamed: R10.1, U5.2
unnamed: R14.1, R16.2, U6.1
unnamed: R17.1, R20.2, U7.1
unnamed: R18.1, R21.2, U7.3
unnamed: R28.1, R29.1, U10.5
unnamed: Rsc1.1, Rsc2.1, Rsc3.1, U10.1, U10.7, U10.8

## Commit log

2019-04-06 Project files added
    [$savepcb.brd, ControllerInput.sch, DigiKey Bom_7812296.xlsx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]
2019-05-01 Removed cutout from manual in InterfaceDriver
    [Encoder.sch, InterfaceDriver.sch, MotionControllerInput.sch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]
2019-05-01 Added 3D STEP file of board
2019-05-02 Updated DigiKey BOM
    [DigiKey Bom_7812296.xlsx]
2019-05-02 Added keep-out area around opto-isolators
    [YAPSCO.kicad_pcb]
